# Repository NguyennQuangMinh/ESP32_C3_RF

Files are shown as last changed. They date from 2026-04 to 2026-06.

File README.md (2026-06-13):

# ESP32_C3_RF

## 🛠️ Project Overview

This project involves designing a 4-layer PCB using Altium Designer for the ESP32_C3_RF. All components, footprints, schematics, and 3D models were custom-created and assembled with me.

## Design Files 

### 🔹 Reversion History Schematic
<p align="center">
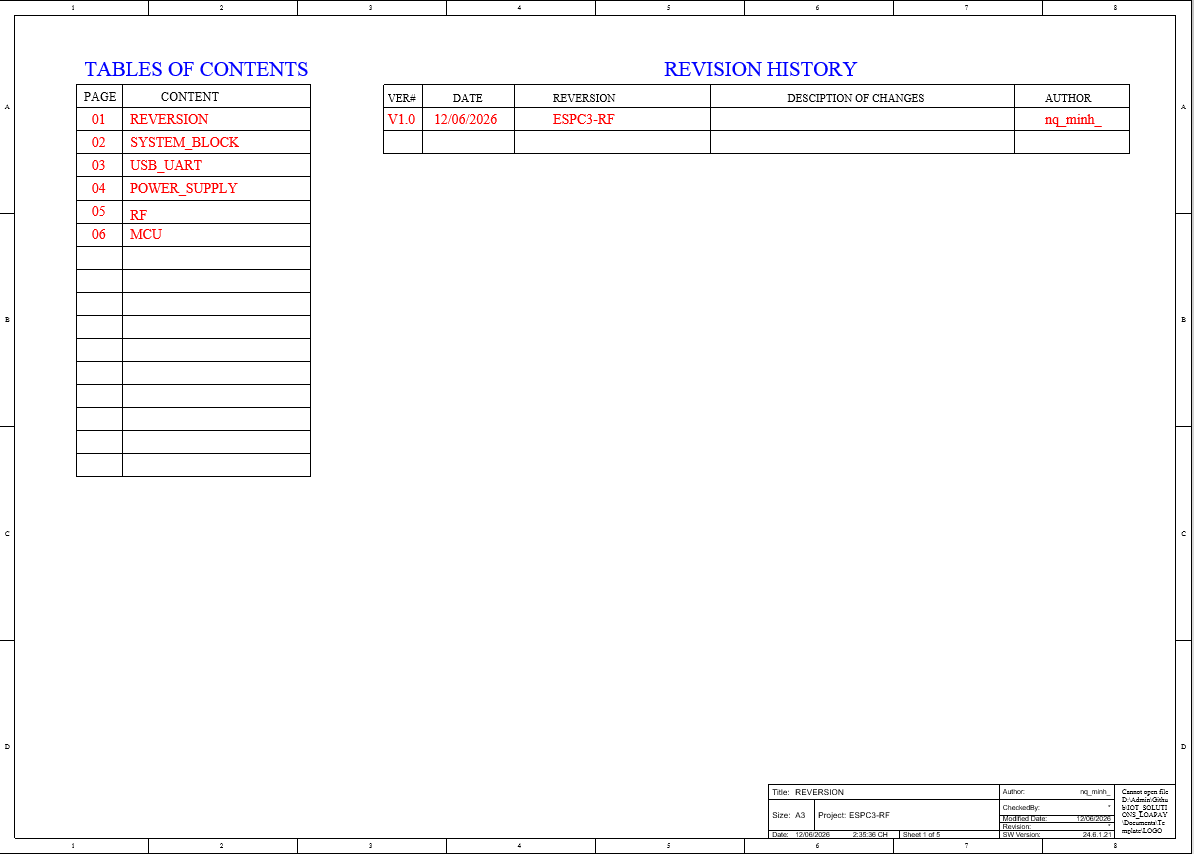
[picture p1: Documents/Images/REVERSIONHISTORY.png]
  
</p>

### 🔹 System Block Schematic
<p align="center">
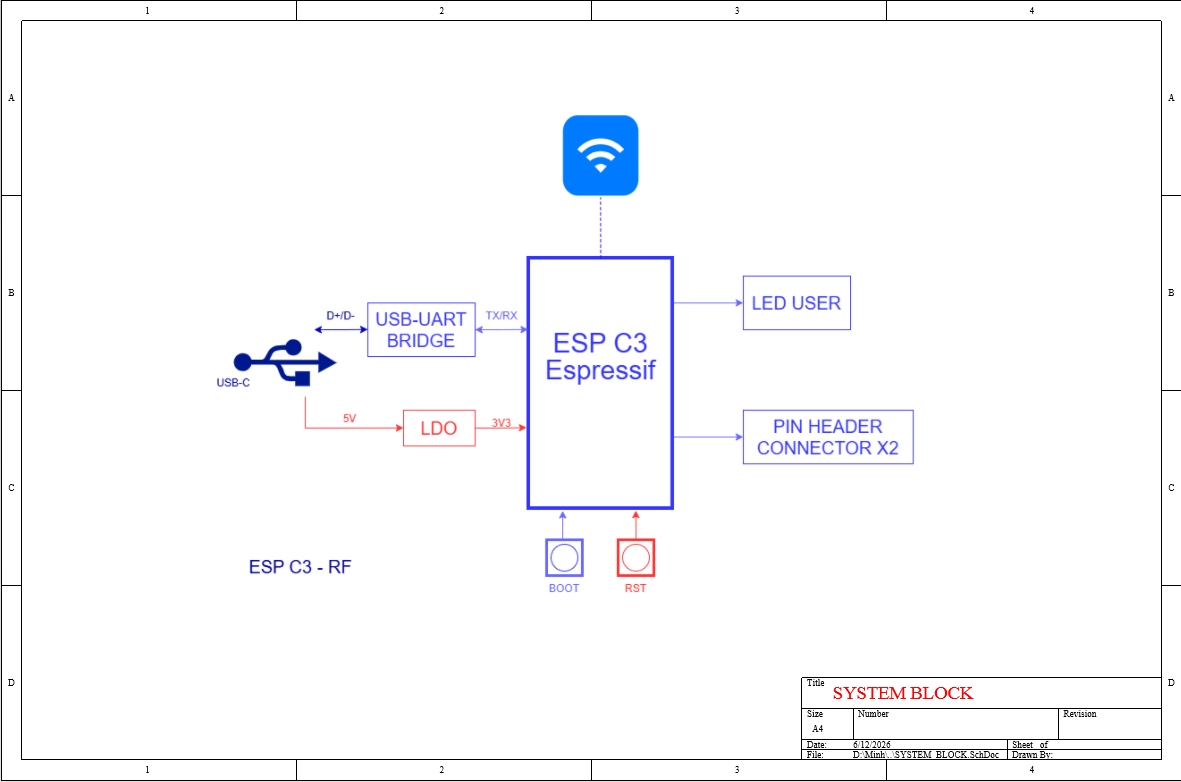
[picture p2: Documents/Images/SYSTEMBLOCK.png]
  
</p>

### 🔹 USB-UART Schematic
<p align="center">
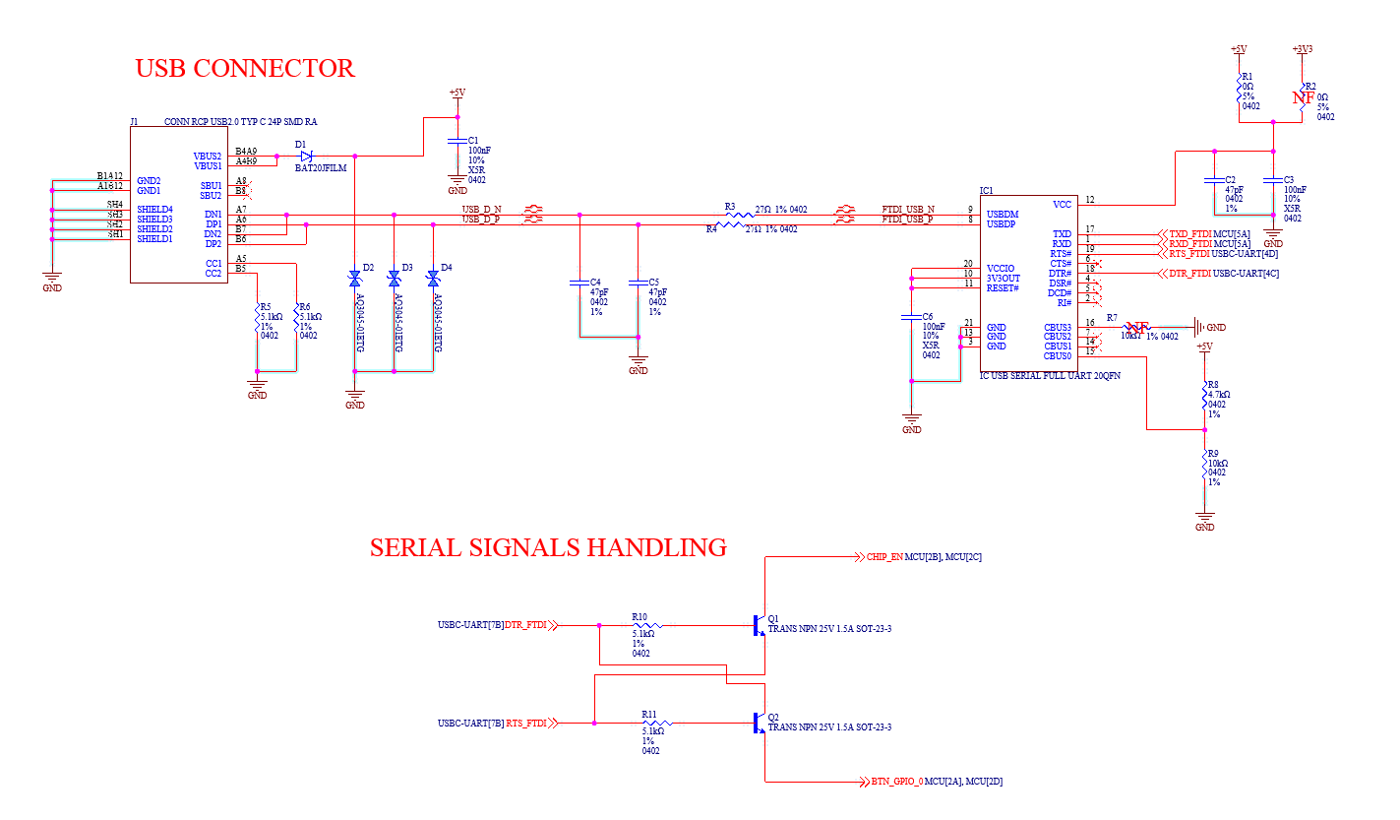
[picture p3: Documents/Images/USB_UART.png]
  
</p>

### 🔹 Power Sharing Schematic
<p align="center">
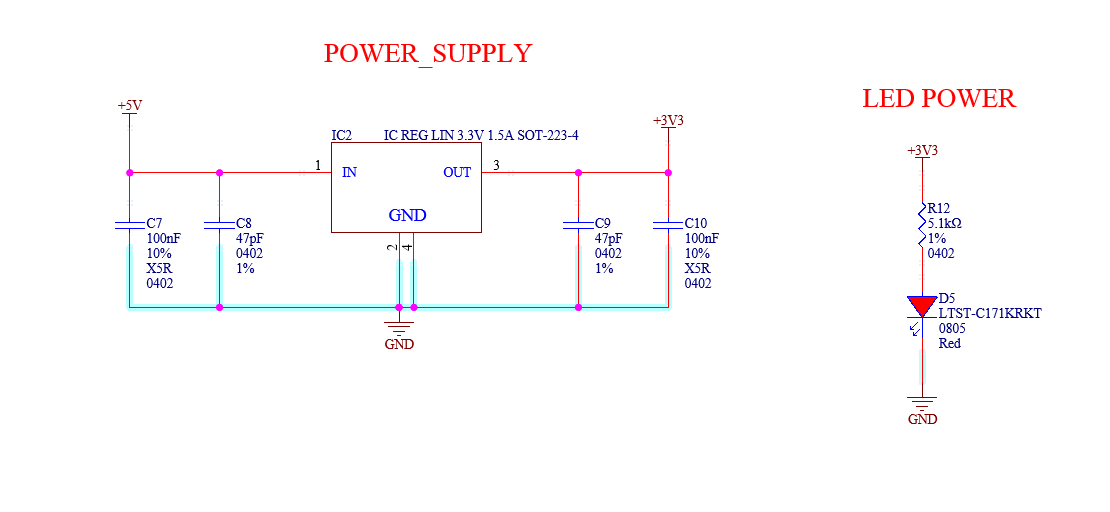
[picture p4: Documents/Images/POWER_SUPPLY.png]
  
</p>

### 🔹 RF 2.4Ghz Antenna Schematic
<p align="center">
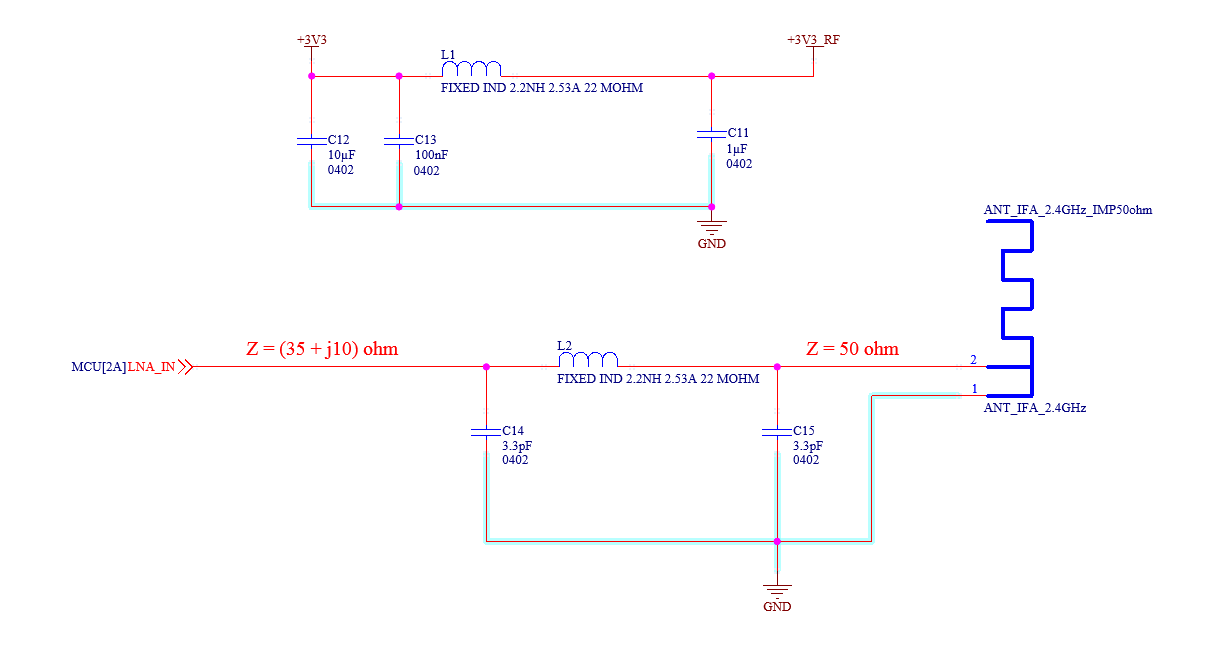
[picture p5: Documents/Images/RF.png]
  
</p>

### 🔹 Peripherals Schematic
<p align="center">
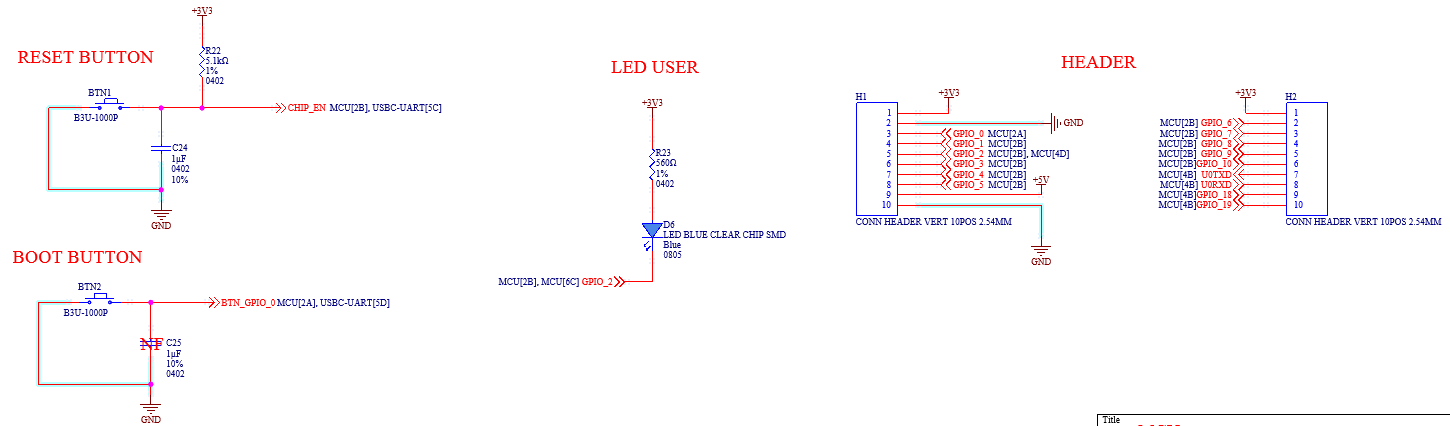
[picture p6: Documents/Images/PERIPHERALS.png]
  
</p>

### 🔹 MCU Schematic
<p align="center">
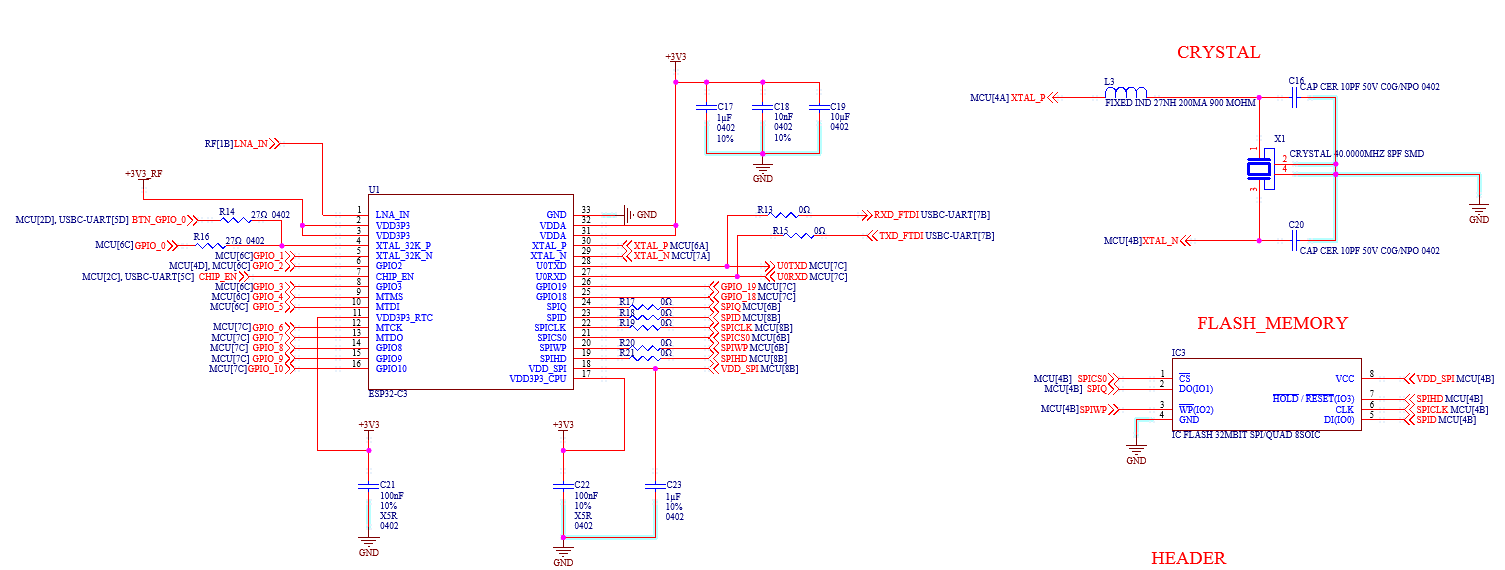
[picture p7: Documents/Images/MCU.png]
  
</p>

### ✅ PCB Overview
<p align="center">
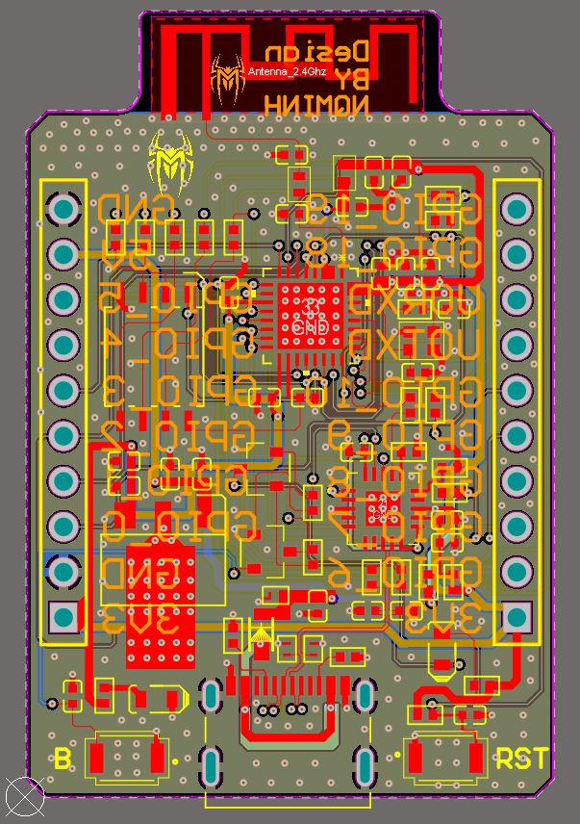
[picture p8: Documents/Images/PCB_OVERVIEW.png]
  
</p>

### ✅ Top Layer
<p align="center">
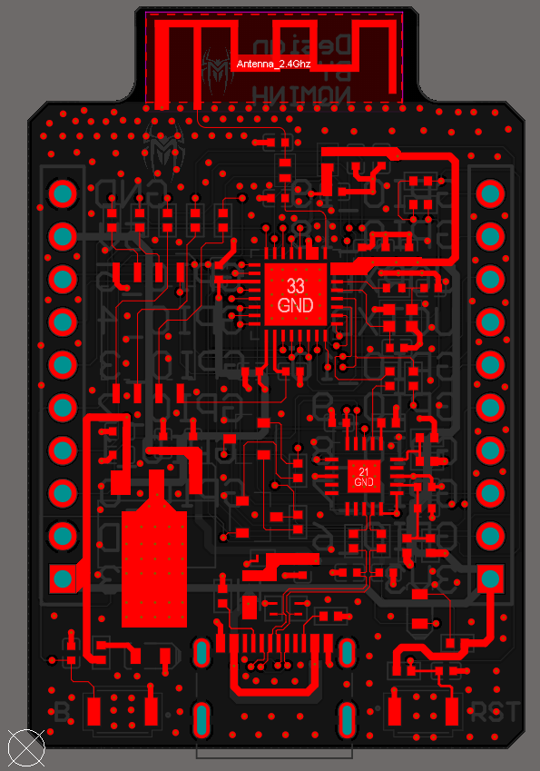
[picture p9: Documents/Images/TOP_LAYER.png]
  
</p>

### ✅ Inner Layer 1
<p align="center">
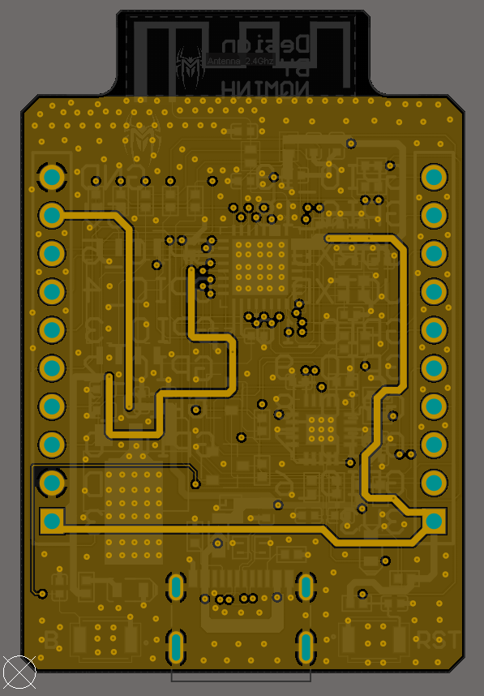
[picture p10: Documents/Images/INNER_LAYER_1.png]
  
</p>

### ✅ Inner Layer 2
<p align="center">
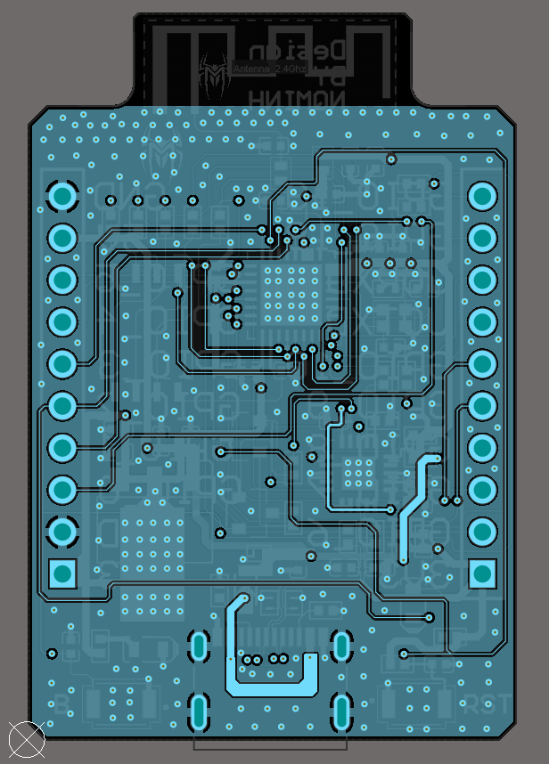
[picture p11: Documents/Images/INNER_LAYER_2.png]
  
</p>

### ✅ Bottom Layer
<p align="center">
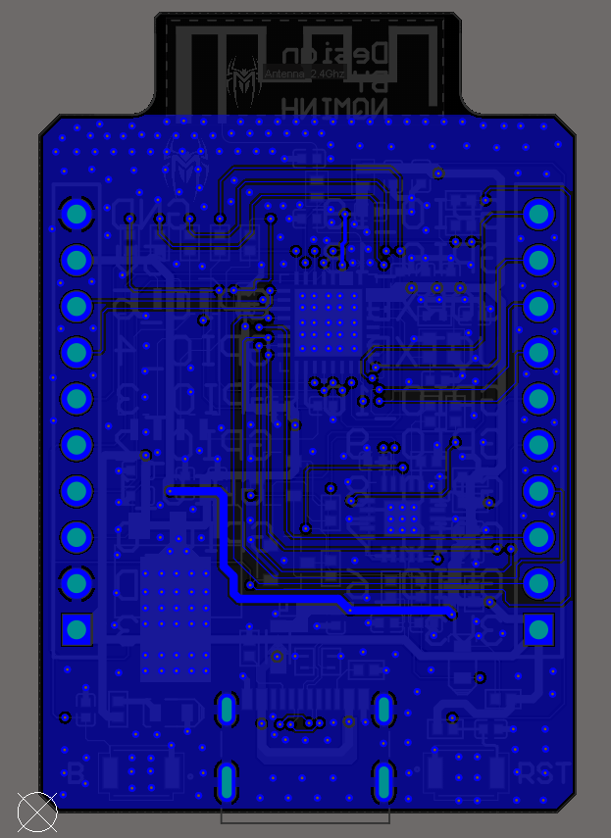
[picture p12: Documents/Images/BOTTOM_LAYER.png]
  
</p>

### ✅ Top Overlay
<p align="center">
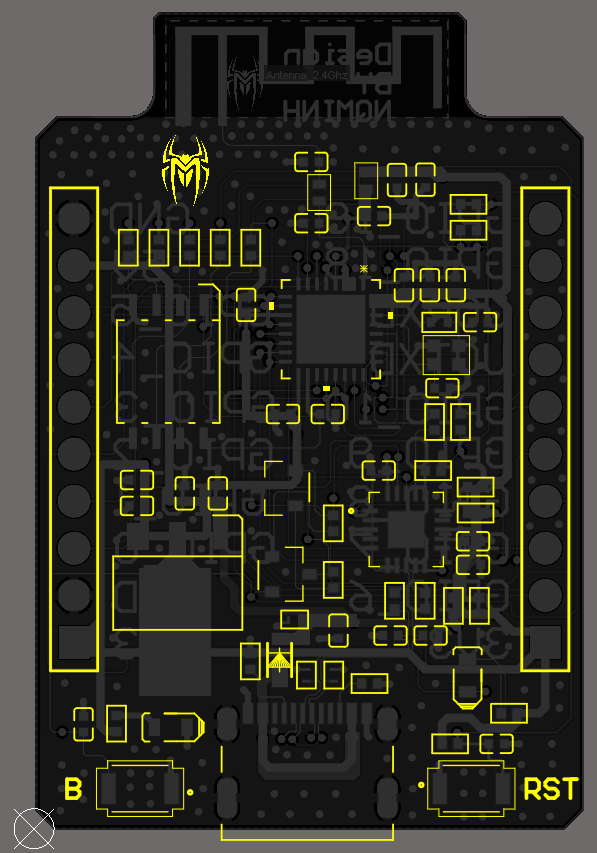
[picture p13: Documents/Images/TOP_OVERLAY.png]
  
</p>

### ✅ Bottom Overlay
<p align="center">
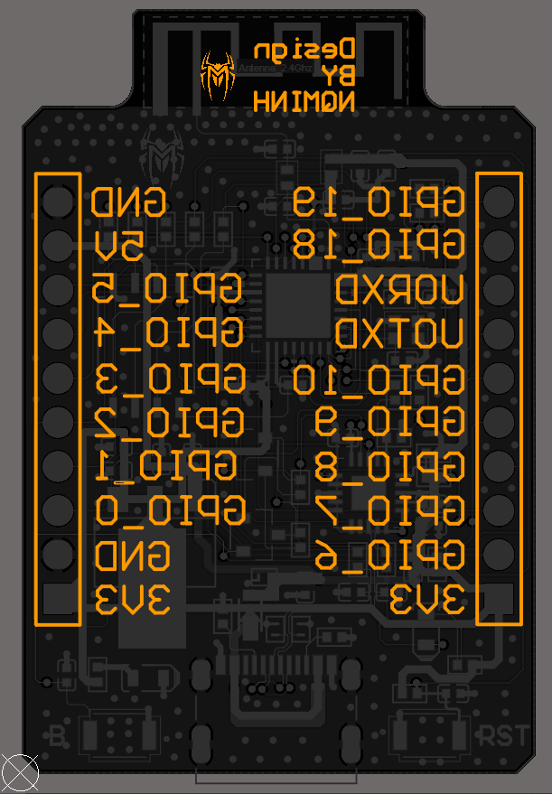
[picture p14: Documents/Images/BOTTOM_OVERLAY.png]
  
</p>

### ✅ 3D Model Top View
<p align="center">
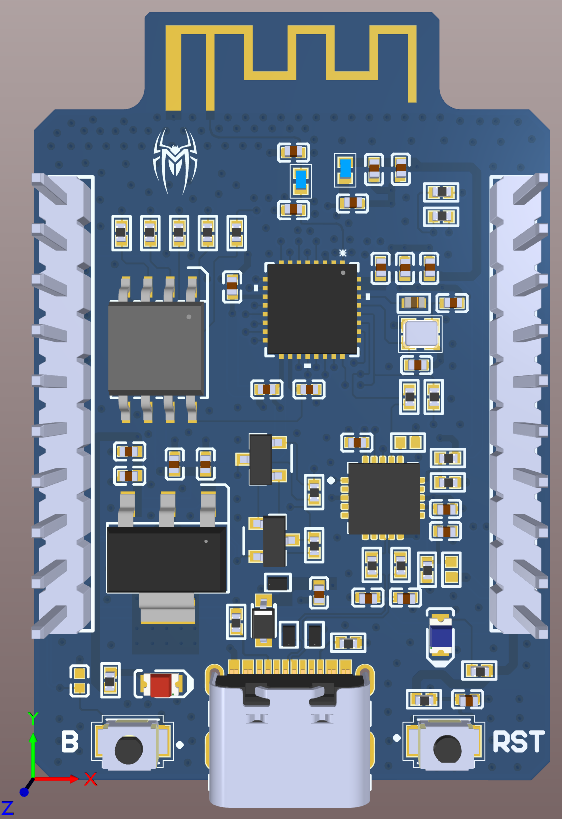
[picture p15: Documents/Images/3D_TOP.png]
  
</p>

### ✅ 3D Model Bottom View
<p align="center">
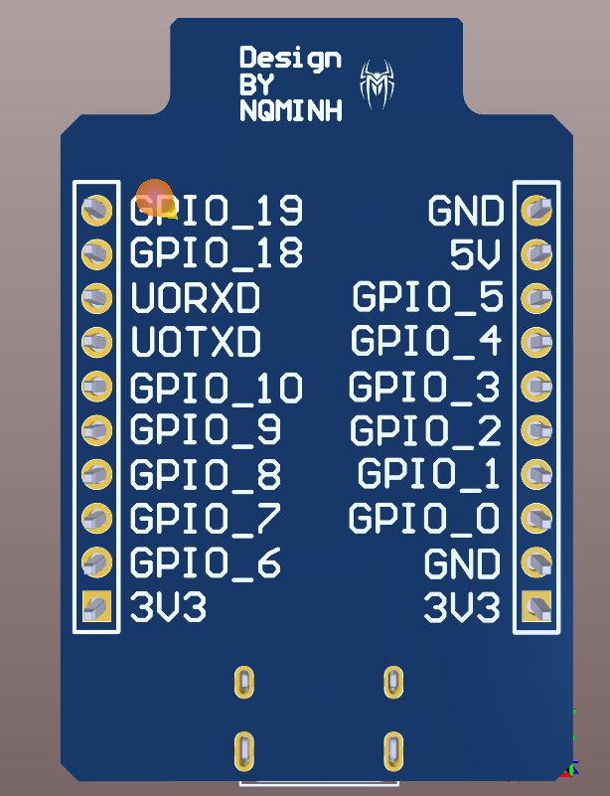
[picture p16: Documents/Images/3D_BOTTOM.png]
  
</p>

### ✅ 3D Model Top View No Body
<p align="center">
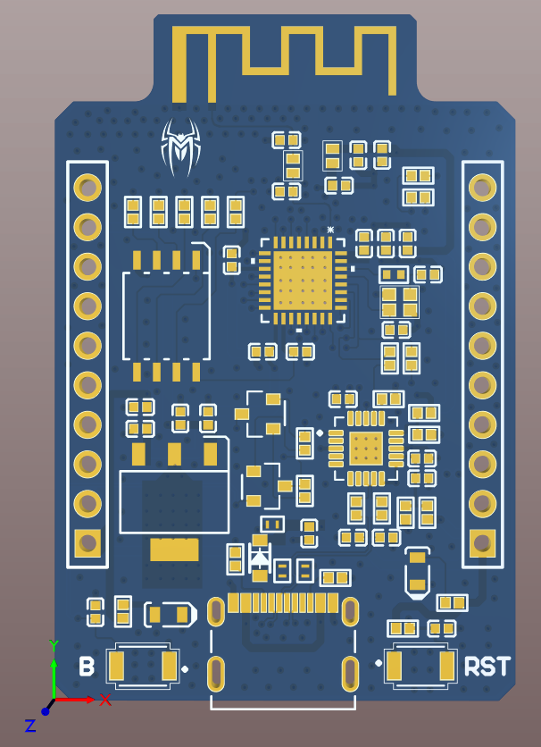
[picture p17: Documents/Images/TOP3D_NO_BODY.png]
  
</p>

## Output Files
### Gerber Files
- Gerber files are used for PCB manufacturing.
### Bill of Materials (BOM)
- Lists all components used in the project.
### NC Drill Files
- Used for drilling holes in the PCB.
### PDF Schematic
- A PDF version of the schematic for easy reference.
### 3D STEP File
- A 3D model of the PCB.
### Assembly Drawings
- Detailed drawings for PCB assembly.
### Pick and Place Files
- Files for automated component placement.

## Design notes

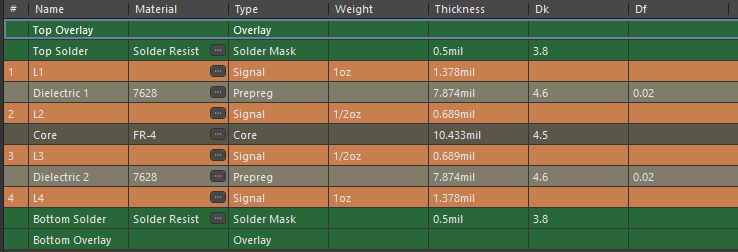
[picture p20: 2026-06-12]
Documents/Images/STACKUP_LAYER.png

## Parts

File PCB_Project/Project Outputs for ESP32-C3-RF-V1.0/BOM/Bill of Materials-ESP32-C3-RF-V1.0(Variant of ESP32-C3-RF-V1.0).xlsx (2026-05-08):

Comment | Description | Designator | Footprint | LibRef | Quantity | LCSC Part | Manufacturer Part Number | Manufacturer | Supplier Part Number | Supplier
ANT_IFA_2.4GHz |  | ANT_IFA_2.4GHz_IMP50ohm | ANT_IFA_2.4GHz | ANT_IFA_2.4GHz | 1
SWITCH TACTILE SPST-NO 0.05A 12V | Switch Tactile N.O. SPST Round Button Solder Tab 12VDC 200000Cycles 1.5N SMD Emboss T/R | BTN1, BTN2 | SW_B3U-1000P | B3U-1000P | 2 | C231329 | B3U-1000P | Omron | SW1020CT-ND | DigiKey
CAP CER 100nF 50V X5R 0402 | 50V 100nF X5R ±10% 0402 Multilayer Ceramic Capacitors MLCC - SMD/SMT ROHS | C1, C3, C6, C7, C10, C13, C21, C22 | C0402 | CC0402KRX5R9BB104 | 8 | C105882 | CC0402KRX5R9BB104 | Yageo Group | 311-3342-2-ND | DigiKey
CAP CER 47PF 50V C0G/NPO 0402 | 50V 47pF NP0 ±1% 0402 Multilayer Ceramic Capacitors MLCC - SMD/SMT ROHS | C2, C4, C5, C8, C9 | C0402 | CC0402FRNPO9BN470 | 5 | C277503 | CC0402FRNPO9BN470 | Yageo Group | 311-1646-1-ND | DigiKey
CAP CER 1UF 10V X5R 0402 | Multilayer Ceramic Capacitors MLCC – SMD/SMT; YAGEO; CC0402KRX5R6BB105; 1 µF; 0402; 10 V; 10 V | C11, C17, C23, C24 | C0402 | CC0402KRX5R6BB105 | 4 | C106254 | CC0402KRX5R6BB105 | Yageo Group | 311-1439-1-ND | DigiKey
CAP CER 10UF 10V X5R 0402 | 10V 10uF X5R ±20% 0402 Multilayer Ceramic Capacitors MLCC - SMD/SMT ROHS | C12, C19 | C0402 | GRM155R61A106ME11D | 2 | C408132 | GRM155R61A106ME11D | Murata | 490-GRM155R61A106ME11DCT-ND | DigiKey
GRM1555C2A3R3CA01D | Cap Ceramic 3.3pF 100V C0G 0.25pF Pad SMD 0402 125C T/R | C14, C15 | C0402 | GRM1555C2A3R3CA01D | 2 | C3861813 | GRM1555C2A3R3CA01D | Murata | 490-7287-1-ND | DigiKey
CAP CER 10PF 50V C0G/NPO 0402 | Ceramic Capacitor, Multilayer, Ceramic, 50V, 1% +Tol, 1% -Tol, C0G, 30ppm/Cel TC, 0.00001uF, Surface Mount, 0402 | C16, C20 | C0402 | CC0402FPNPO9BN100 | 2 | C3896396 | CC0402FPNPO9BN100 | Yageo Group | 13-CC0402FPNPO9BN100CT-ND | DigiKey
CAP CER 10000PF 16V X7R 0402 | Multilayer Ceramic Capacitors MLCC - SMD/SMT 16V 0.01uF X7R 0402 10% | C18 | C0402 | CC0402KRX7R7BB103 | 1 | C327009 | CC0402KRX7R7BB103 | Yageo Group | 311-1042-1-ND | DigiKey
BAT20JFILM | BAT20J Series 23 V 1 A Surface Mount Switching Schottky Diode - SOD-323 | D1 | SOD-323 | BAT20JFILM | 1 | C155590 | BAT20JFILM | STMicroelectronics | 497-3381-1-ND | DigiKey
TVS DIODE 5.3VWM 12VC SOD882 | Bi 30Kv 5V 0.35Pf Automotve Tvs Sod882/ T&r Rohs Compliant: Yes |Littelfuse AQ3045-01ETG | D2, D3, D4 | RTVS_SOD882_LTF-L | AQ3045-01ETG | 3 |  | AQ3045-01ETG | Littelfuse | F9321CT-ND | DigiKey
LTST-C171KRKT | LED red 0805 wavelength 631nm light intensity 54mcd Front Mounting | D5 | LED_LTST-C171_LTO-L | LTST-C171KRKT | 1 | C284871 | LTST-C171KRKT | Diodes Inc. | 160-1427-1-ND | DigiKey
LED BLUE CLEAR CHIP SMD | LED blue LED0805 wavelength 465~475nm light intensity 28~180mcd vertical sticker | D6 | LED_0805_BLUE | LTST-C171TBKT | 1 | C98225 | LTST-C171TBKT | Diodes Inc. | 160-1645-1-ND | DigiKey
CONN HEADER VERT 10POS 2.54MM | Conn Unshrouded Header HDR 10 POS 2.54mm Solder ST Top Entry Thru-Hole Bag | H1, H2 | Header 1*10 2.54mm | PH1-10-UA | 2 | C3330527 | PH1-10-UA | Adam Tech | 2057-PH1-10-UA-ND | DigiKey
IC USB SERIAL FULL UART 20QFN | Tape & Reel (TR) 2006 UART USB 2.0 interface controller 3.3V~5V 4mm 8mA 12Mbps | IC1 | QFN50P400X400X80-21N | FT231XQ-R | 1 | C132159 | FT231XQ-R | FTDI | 768-1128-6-ND | DigiKey
IC REG LIN 3.3V 1.5A SOT-223-4 | 1.5-A, 20-V, low-dropout voltage regulator with reverse current & reverse voltage protection | IC2 | DCY4_TEX-L | TL1963A-33DCYR | 1 | C181262 | TL1963A-33DCYR | Texas Instruments | 296-24897-1-ND | DigiKey
IC FLASH 32MBIT SPI/QUAD 8SOIC | NOR Flash Serial (SPI, Dual SPI, Quad SPI) 3V/3.3V 32M-bit 4M x 8 6ns 8-Pin SOIC T/R | IC3 | SOIC-8_5P28X5P28_WIN-L | W25Q32JVSSIQ TR | 1 | C179173 | W25Q32JVSSIQ TR | Winbond | 256-W25Q32JVSSIQTRCT-ND | DigiKey
CONN RCP USB2.0 TYP C 24P SMD RA | USB Connector, USB Type C, USB 2.0, Receptacle, 16 Ways, Surface Mount, Through Hole Mount | J1 | MOLEX_2171790001 | 217179-0001 | 1 | 2171790001 | 217179-0001 | Molex | 900-2171790001DKR-ND | DigiKey
FIXED IND 2.2NH 2.53A 22 MOHM | General Purpose Inductor, 0.0022uH, 2%, 1 Element, Wirewound-Core, Reflow soldering, 1005/0402 | L1, L2 | INDC1006X60N | LQW15AN2N2G80D | 2 |  | LQW15AN2N2G80D | Murata | 490-LQW15AN2N2G80DCT-ND | DigiKey
FIXED IND 27NH 200MA 900 MOHM | General Purpose Inductor, 0.027uH, 5%, 1 Element, Ceramic-Core, SMD, 0402 | L3 | IND_L-0402_JOT-L | LRC0402CJ27NGV001T | 1 | C17449954 | LRC0402CJ27NGV001T | Knowles | 712-LRC0402CJ27NGV001TCT-ND | DigiKey
TRANS NPN 25V 1.5A SOT-23-3 | TRANS NPN 25V 1.5A SOT23-3 / Bipolar (BJT) Transistor NPN 25 V 1.5 A 100MHz 300 mW Surface Mount SOT-23-3 | Q1, Q2 | TRANS_SS8050-G | SS8050-G | 2 | C3199946 | SS8050-G | Comchip | 641-1790-1-ND | DigiKey
RES 0 OHM JUMPER 1/16W 0402 | GENERAL PURPOSE CHIP RESISTOR Metal Glaze/thick Film, 0.0625W, 0ohm, Surface Mount, 0402 | R1, R13, R15, R17, R18, R19, R20, R21 | R0402 | RC0402JR-070RL | 8 | C60485 | RC0402JR-070RL | Yageo Group | 311-0.0JRCT-ND | DigiKey
RES SMD 27 OHM 1% 1/16W 0402 | 62.5mW Thin Film Resistor ±50ppm/℃ ±1% 27Ω 0402 Chip Resistor - Surface Mount ROHS | R3, R4, R14, R16 | R0402 | RT0402FRE0727RL | 4 |  | RT0402FRE0727RL | Yageo Group | YAG3343CT-ND | DigiKey
RES 5.1kΩ ±1% 62.5mW 0402 | 62.5mW Thick Film Resistors 50V ±100ppm/℃ ±1% 5.1kΩ 0402 Chip Resistor - Surface Mount ROHS | R5, R6, R10, R11, R12, R22 | R0402 | RC0402FR-075K1L | 6 | [NoParam], C105872 | RC0402FR-075K1L | Yageo Group | 311-5.10KLRCT-ND | DigiKey
RES SMD 4.7K OHM 1% 1/16W 0402 | Chip Resistor with Ni/Au Terminations Thick Film 0402 4.7kOhm 1% Paper T/R | R8 | R0402 | AR0402FR-074K7L | 1 | C4042400 | AR0402FR-074K7L | Yageo Group | 13-AR0402FR-074K7LCT-ND | DigiKey
RES SMD 10K OHM 1% 1/16W 0402 | Chip Resistor with Ni/Au Terminations Thick Film 0402 10kOhm 1% Paper T/R | R9 | R0402 | AR0402FR-0710KL | 1 | C4322213 | AR0402FR-0710KL | Yageo Group | 13-AR0402FR-0710KLCT-ND | DigiKey
RES 560 OHM 1% 1/16W 0402 | RC Series 0402 0.063 W 560 Ohm ±1% ±100 ppm/°C SMT Thick Film Chip Resistor | R23 | R0402 | RC0402FR-13560RL | 1 | C4098662 | RC0402FR-13560RL | Yageo Group | 13-RC0402FR-13560RLCT-ND | DigiKey
ESP32-C3 | 400KB 22 3V~3.6V RISC-V 160MHz QFN-32-EP(5x5) Microcontroller Units (MCUs/MPUs/SOCs) ROHS | U1 | ESP-C3 | ESP32-C3 | 1 | C2838500 | ESP32-C3 | Espressif Systems | 1904-ESP32-C3CT-ND | DigiKey
CRYSTAL 40.0000MHZ 8PF SMD | Crystal 40MHz ±10ppm (Tol) ±10ppm (Stability) 8pF 50Ohm 4-Pin CSMD T/R | X1 | OSC_XRCGB40M000F1S1BR0 | XRCGB40M000F1S1BR0 | 1 | C1870451 | XRCGB40M000F1S1BR0 | Murata | 490-XRCGB40M000F1S1BR0CT-ND | DigiKey

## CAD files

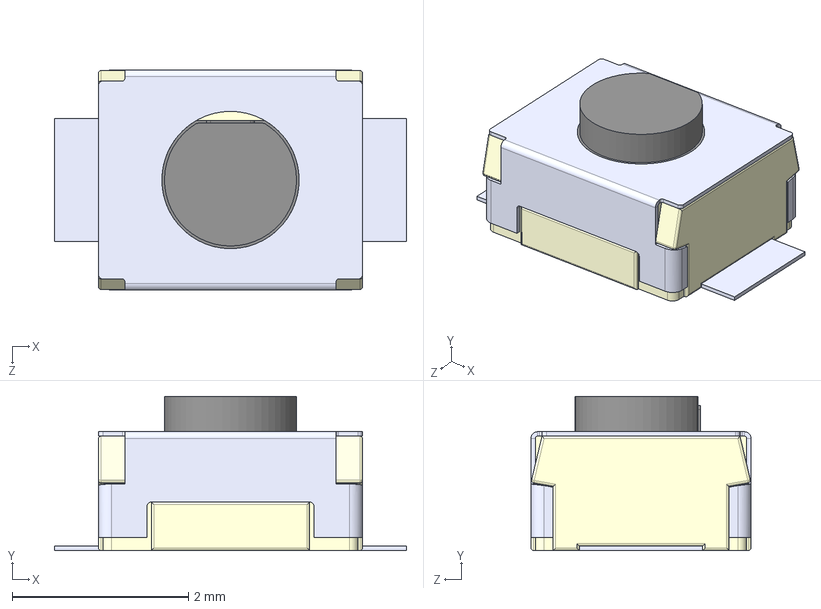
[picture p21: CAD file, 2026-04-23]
Documents/TMP/3D Body/B3U_1000P/B3U-1000P.STEP
4.00 x 1.75 x 2.50 mm

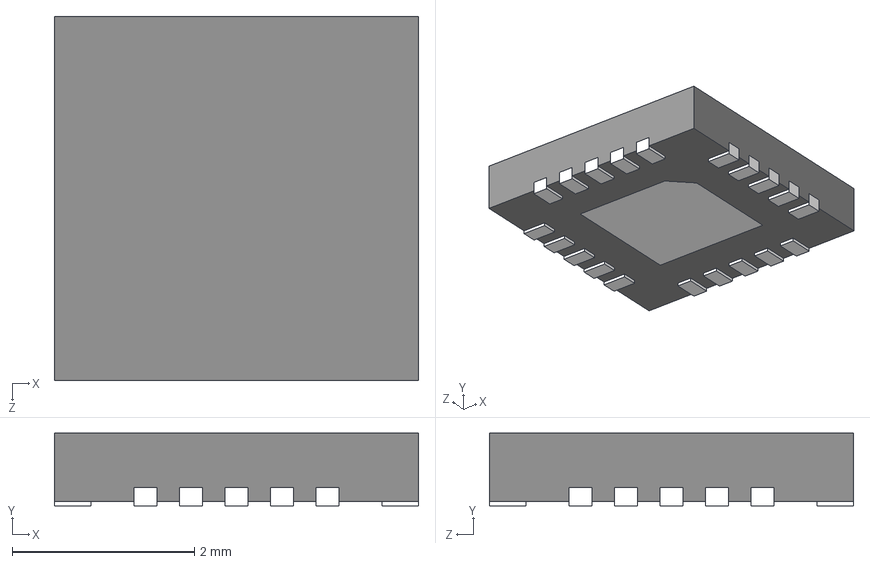
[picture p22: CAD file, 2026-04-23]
Documents/TMP/3D Body/FT231XQ_R/FT231XQ-R.STEP
4.00 x 0.8 x 4.00 mm

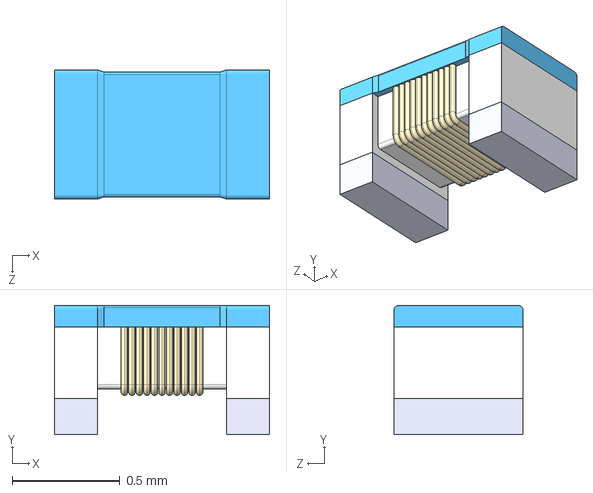
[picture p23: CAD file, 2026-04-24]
Documents/TMP/3D Body/LQW15AN2N2G80D/INDC1006X60N.step
1.00 x 0.6 x 0.6 mm

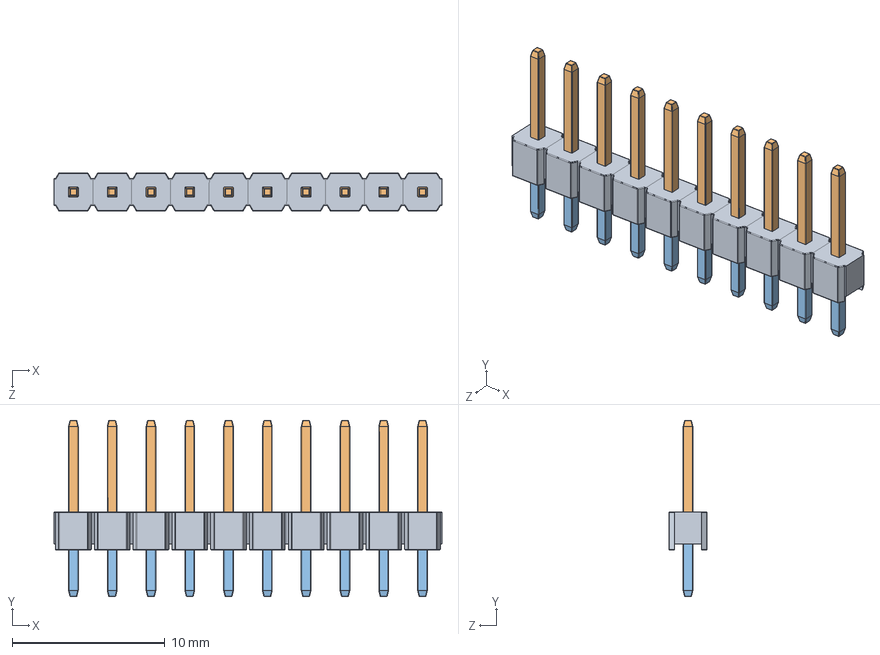
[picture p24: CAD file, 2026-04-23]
Documents/TMP/3D Body/PH1-10-UA.STEP
25.4 x 11.6 x 2.50 mm

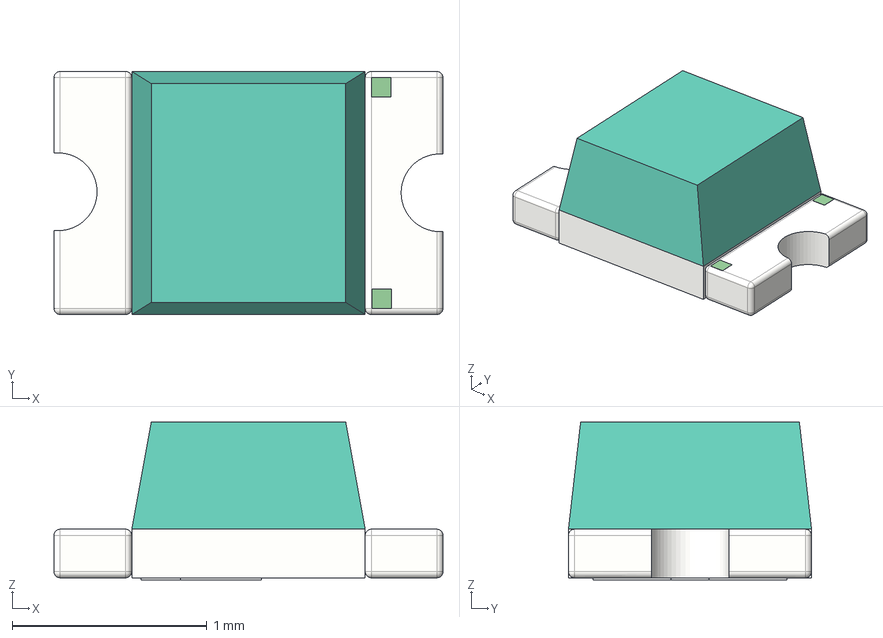
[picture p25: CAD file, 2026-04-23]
Documents/TMP/3D Body/smd-led-0805-3.snapshot.3/LED-0805-glass.step
2.00 x 1.25 x 0.81 mm
ColorGlass

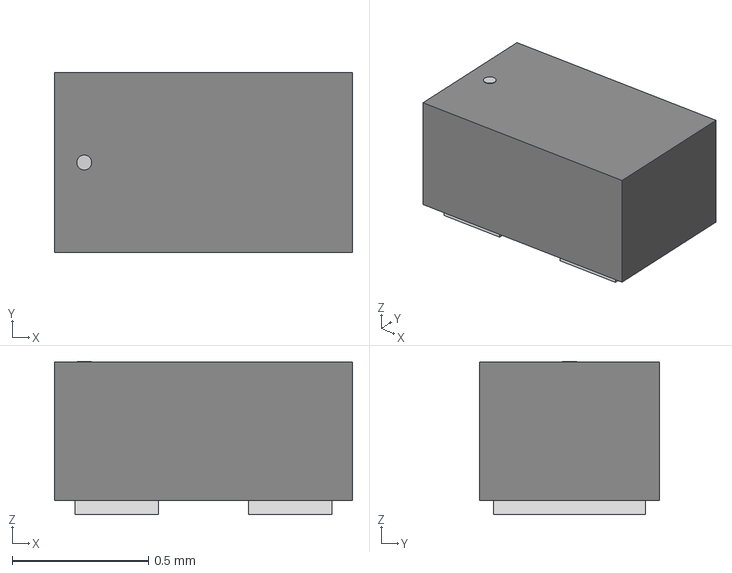
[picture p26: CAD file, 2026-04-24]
Documents/TMP/AQ3045_01ETG/Altium/AQ3045-01ETG/RTVS_SOD882_LTF.step
1.09 x 0.66 x 0.561 mm

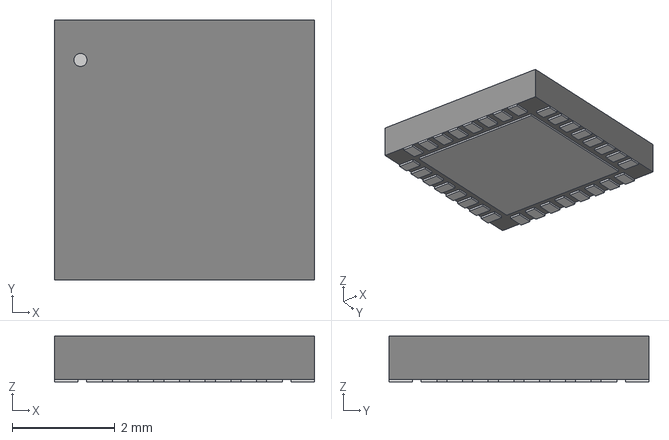
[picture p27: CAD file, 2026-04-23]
Documents/TMP/ESP32_C3/Altium/ESP32-C3/QFN32_5X5_EXP.step
5.05 x 5.05 x 0.892 mm

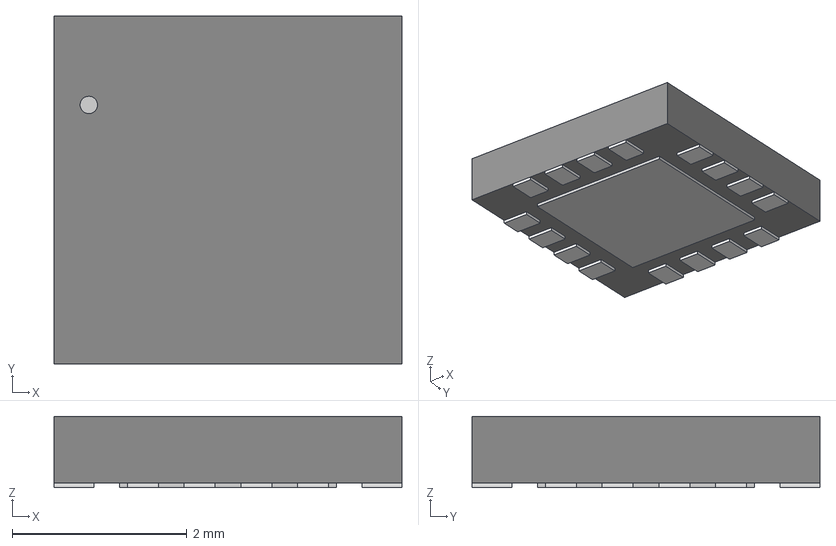
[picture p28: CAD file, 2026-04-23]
Documents/TMP/FT230XQ_R/Altium/FT230XQ-R/QFN-16_FTD.step
3.99 x 3.99 x 0.815 mm

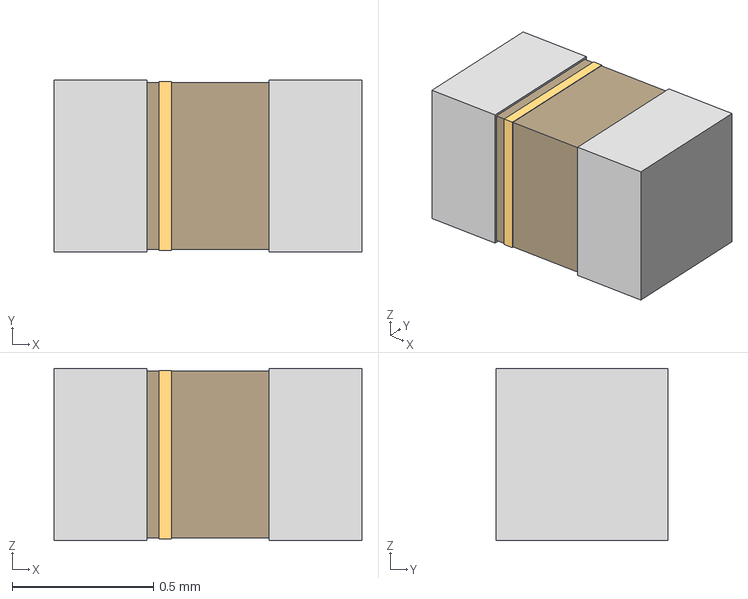
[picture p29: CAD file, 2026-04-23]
Documents/TMP/L_07C27NJV6T/Altium/IND_L-0402_JOT.step
1.09 x 0.61 x 0.61 mm

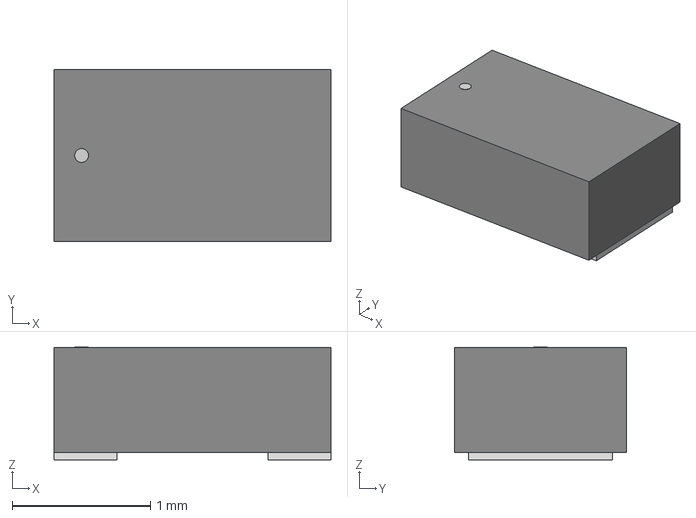
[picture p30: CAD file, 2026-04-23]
Documents/TMP/LTST_C171KRKT/Altium/LTST-C171KRKT/LED_LTST-C171_LTO.step
2.01 x 1.24 x 0.815 mm

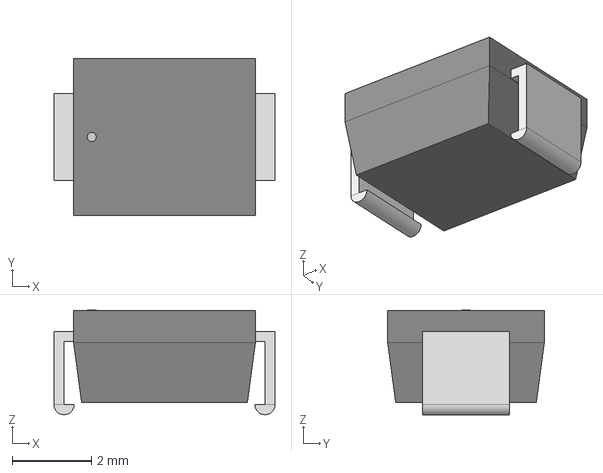
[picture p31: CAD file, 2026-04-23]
Documents/TMP/SMBJ5_0A_TR/Altium/SMBJ5-0A-TR/SMB_STM.step
5.59 x 3.96 x 2.64 mm

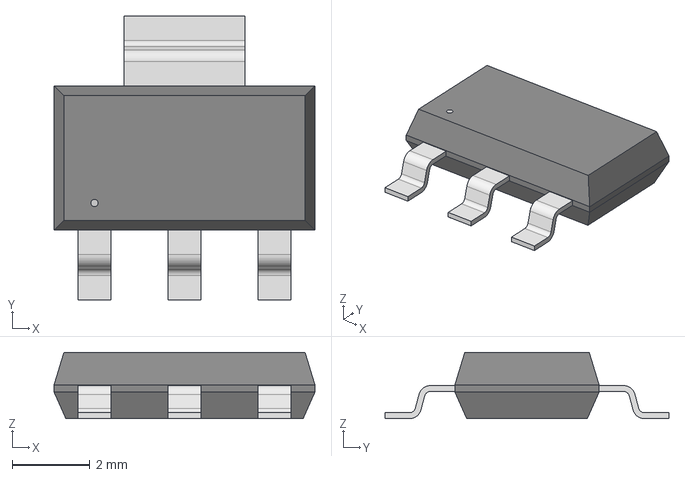
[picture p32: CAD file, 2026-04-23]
Documents/TMP/TL1963A_33DCYR/Altium/TL1963A-33DCYR/DCY4_TEX.step
6.71 x 7.29 x 1.70 mm

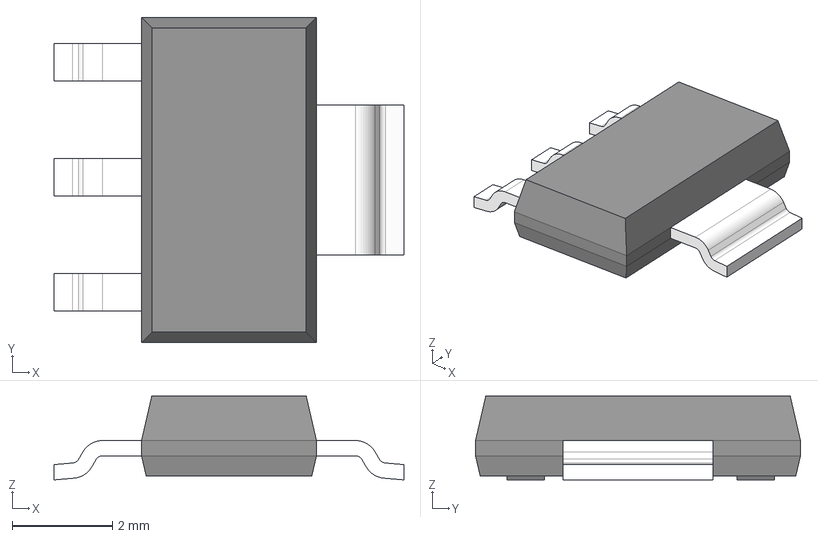
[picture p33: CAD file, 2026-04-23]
Documents/TMP/TL1963A_33DCYR/DCY0004A.stp
7.00 x 6.50 x 1.68 mm
BODY-SOT
LEAD-SOT x 3
LEAD-SOT-WIDE
PIN1-ID

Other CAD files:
Documents/TMP/AQ3045_01ETG/RTVS_SOD882_LTF.step
Documents/TMP/ESP32_C3/QFN32_5X5_EXP.step
Documents/TMP/FT230XQ_R/QFN-16_FTD.step
Documents/TMP/L_07C27NJV6T/IND_L-0402_JOT.step
Documents/TMP/SMBJ5_0A_TR/SMB_STM.step
Documents/TMP/3D Body/2171790001/2171790001.STEP
Documents/TMP/3D Body/C0402C152J5GACTU.STEP
Documents/TMP/3D Body/PH1-10-UA.STL
Documents/TMP/3D Body/SS8050-G--3DModel-STEP-1.STEP
Documents/TMP/3D Body/smd-led-0805-3.snapshot.3/LED-0805-blue.step
Documents/TMP/3D Body/smd-led-0805-3.snapshot.3/LED-0805-emerald.step
Documents/TMP/3D Body/smd-led-0805-3.snapshot.3/LED-0805-green.step
Documents/TMP/3D Body/smd-led-0805-3.snapshot.3/LED-0805-orange.step
Documents/TMP/3D Body/smd-led-0805-3.snapshot.3/LED-0805-red.step
Documents/TMP/3D Body/smd-led-0805-3.snapshot.3/LED-0805-yellow.step
Documents/TMP/W25Q32JVSSIQ/Altium/W25Q32JVSSIQ/SOIC-8_5P28X5P28_WIN.step
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

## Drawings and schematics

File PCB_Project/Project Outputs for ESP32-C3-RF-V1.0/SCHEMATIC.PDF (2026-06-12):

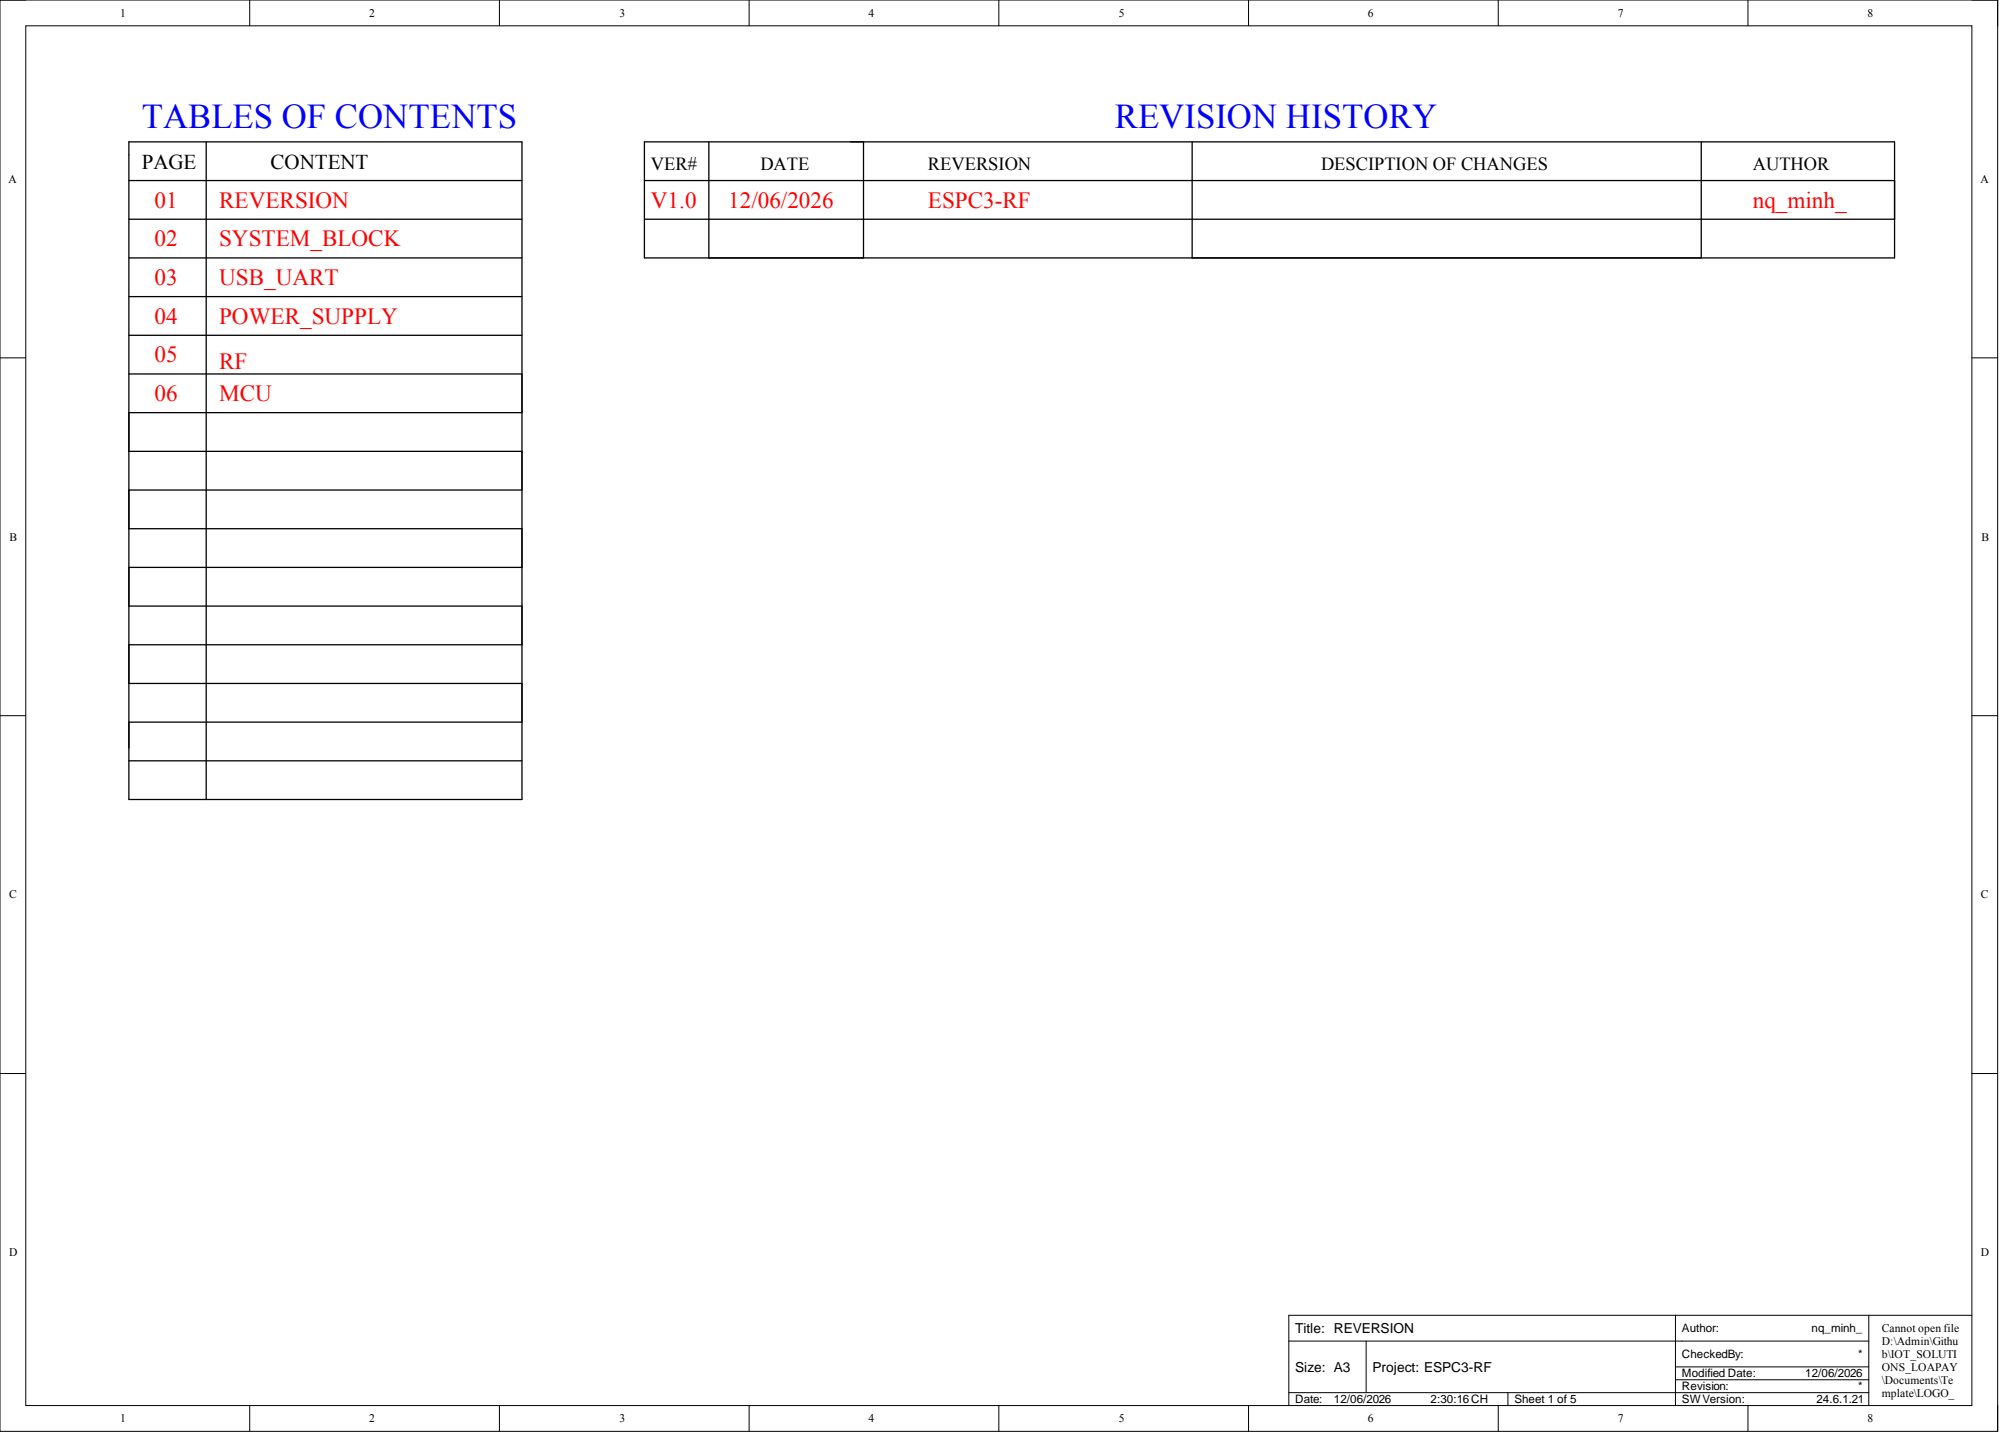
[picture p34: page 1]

02 | SYSTEM_BLOCK
03 | USB_UART
04 | POWER_SUPPLY
05 | RF
06 | MCU

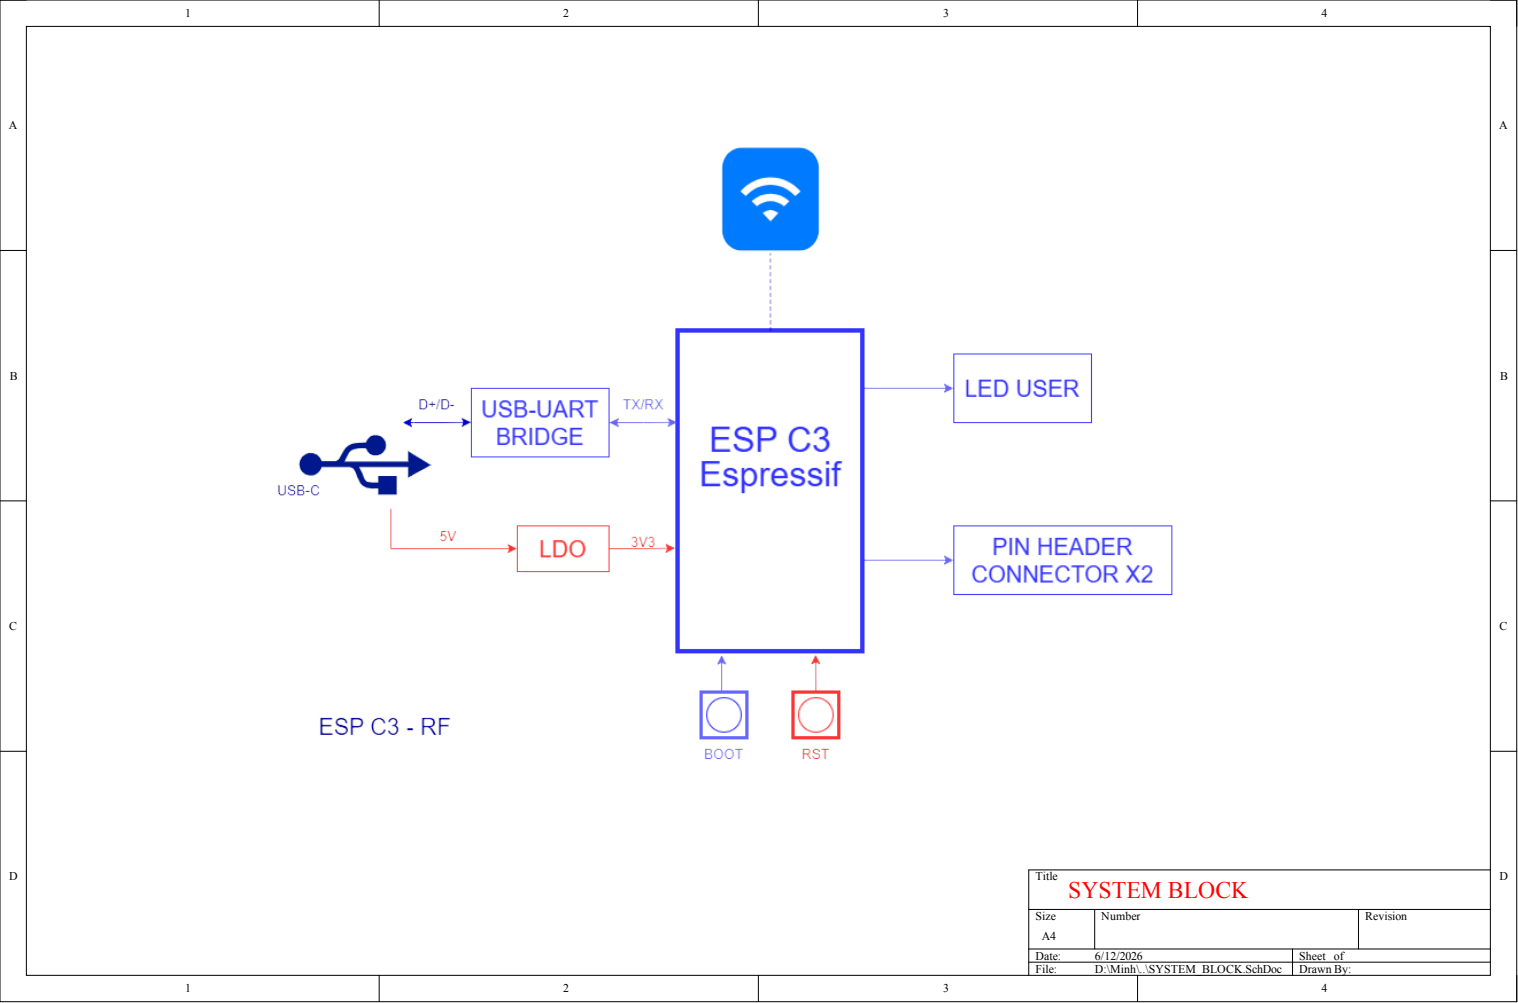
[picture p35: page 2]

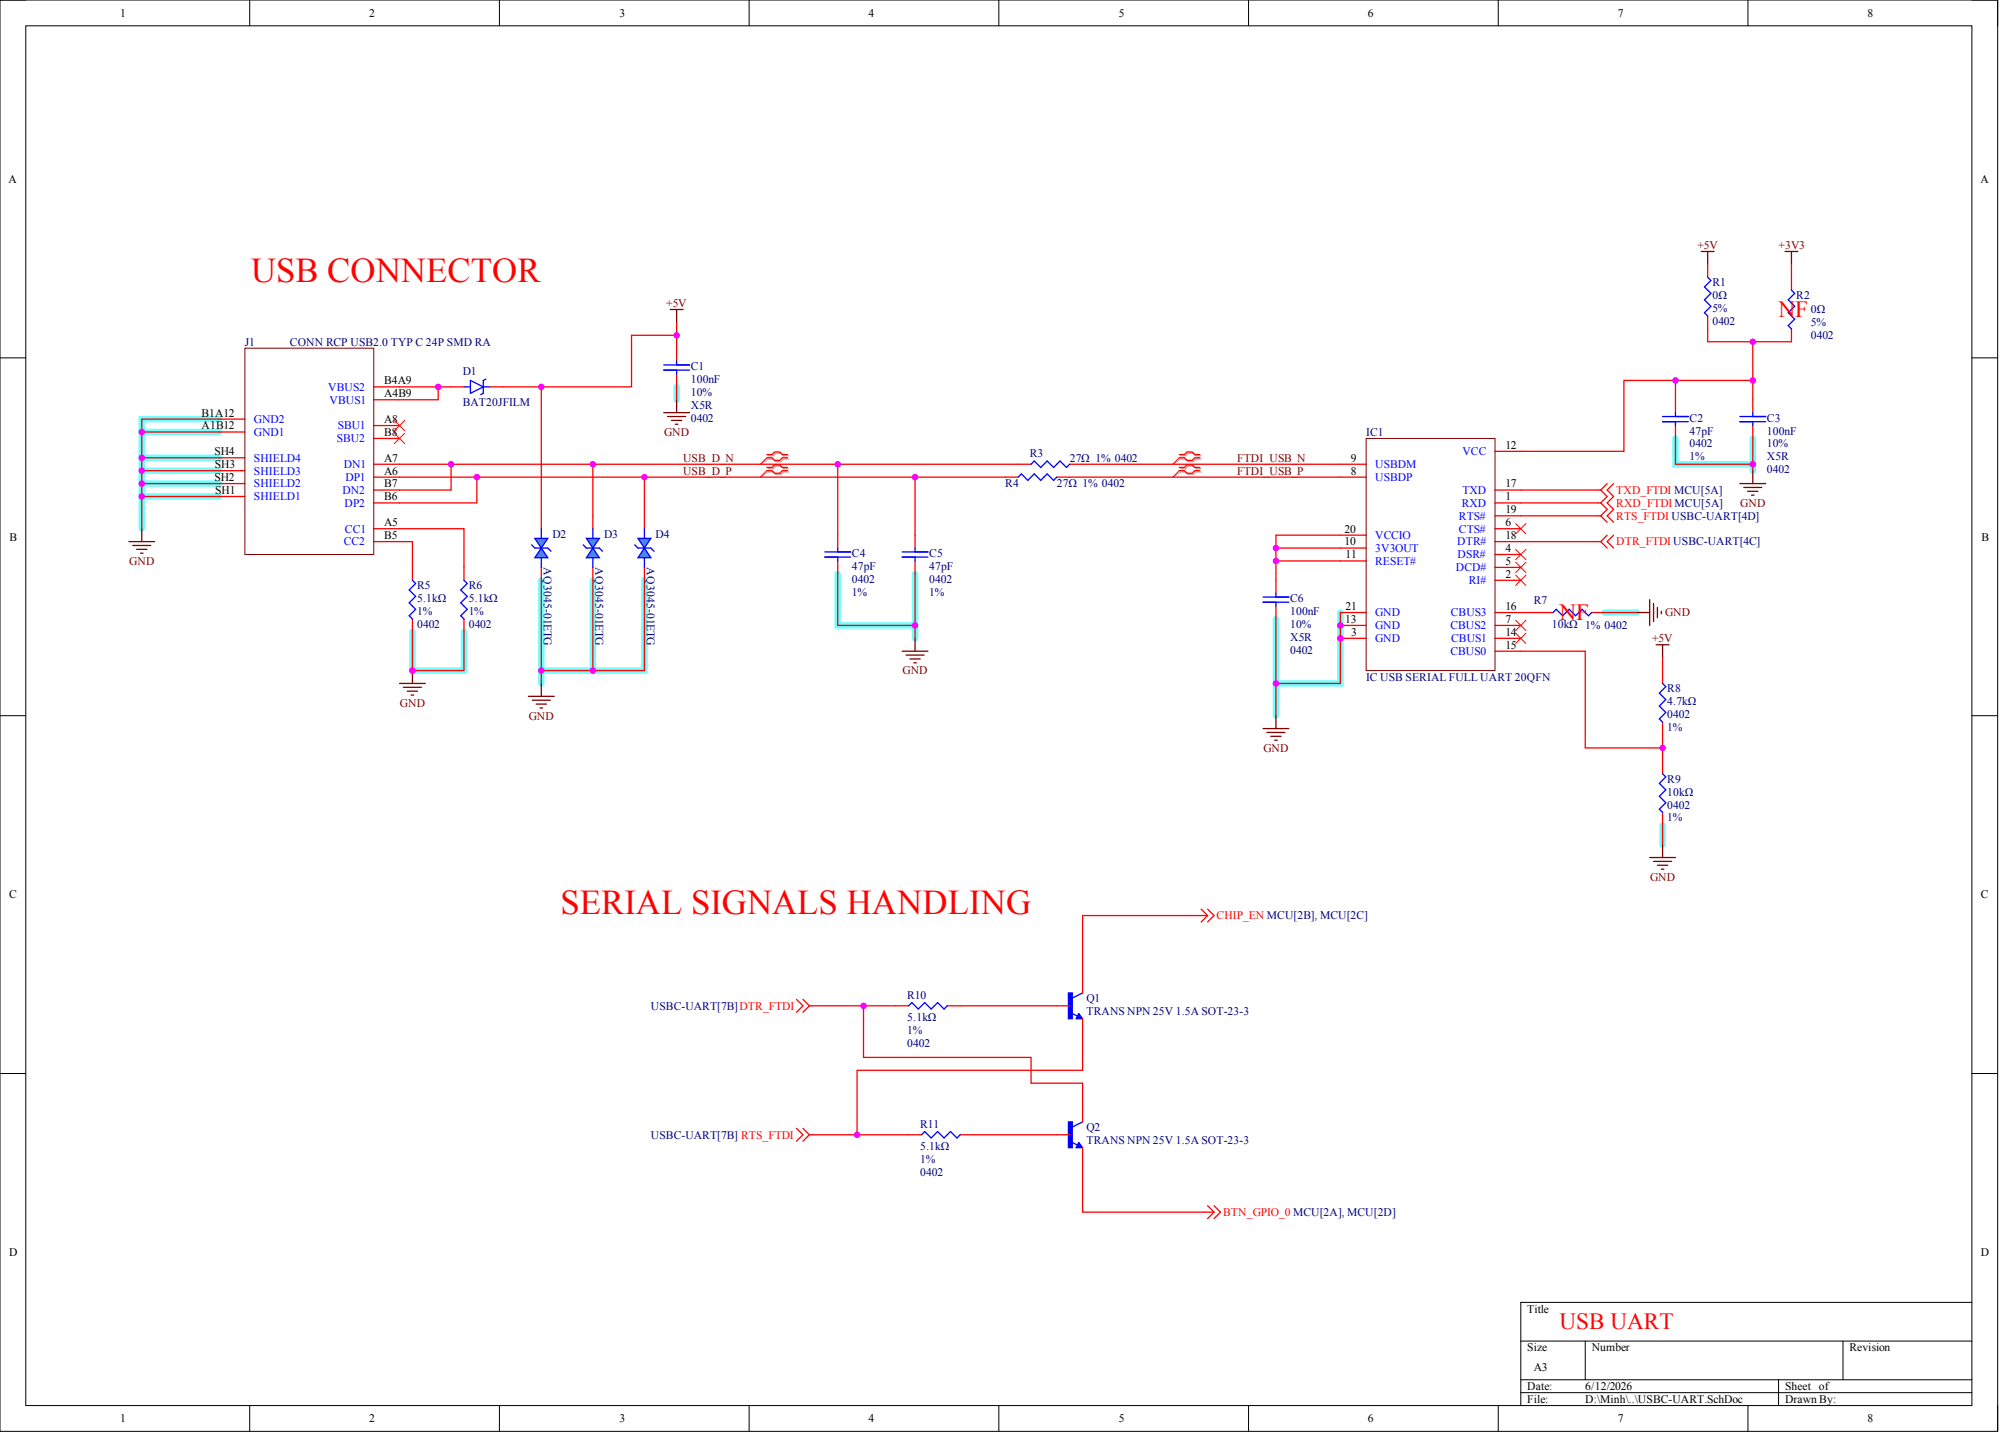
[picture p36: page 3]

1 0
1 1

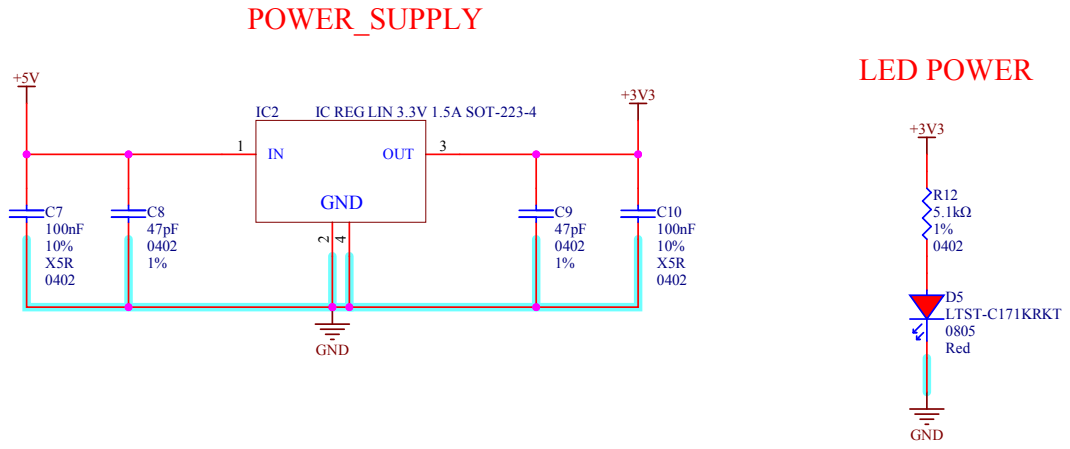
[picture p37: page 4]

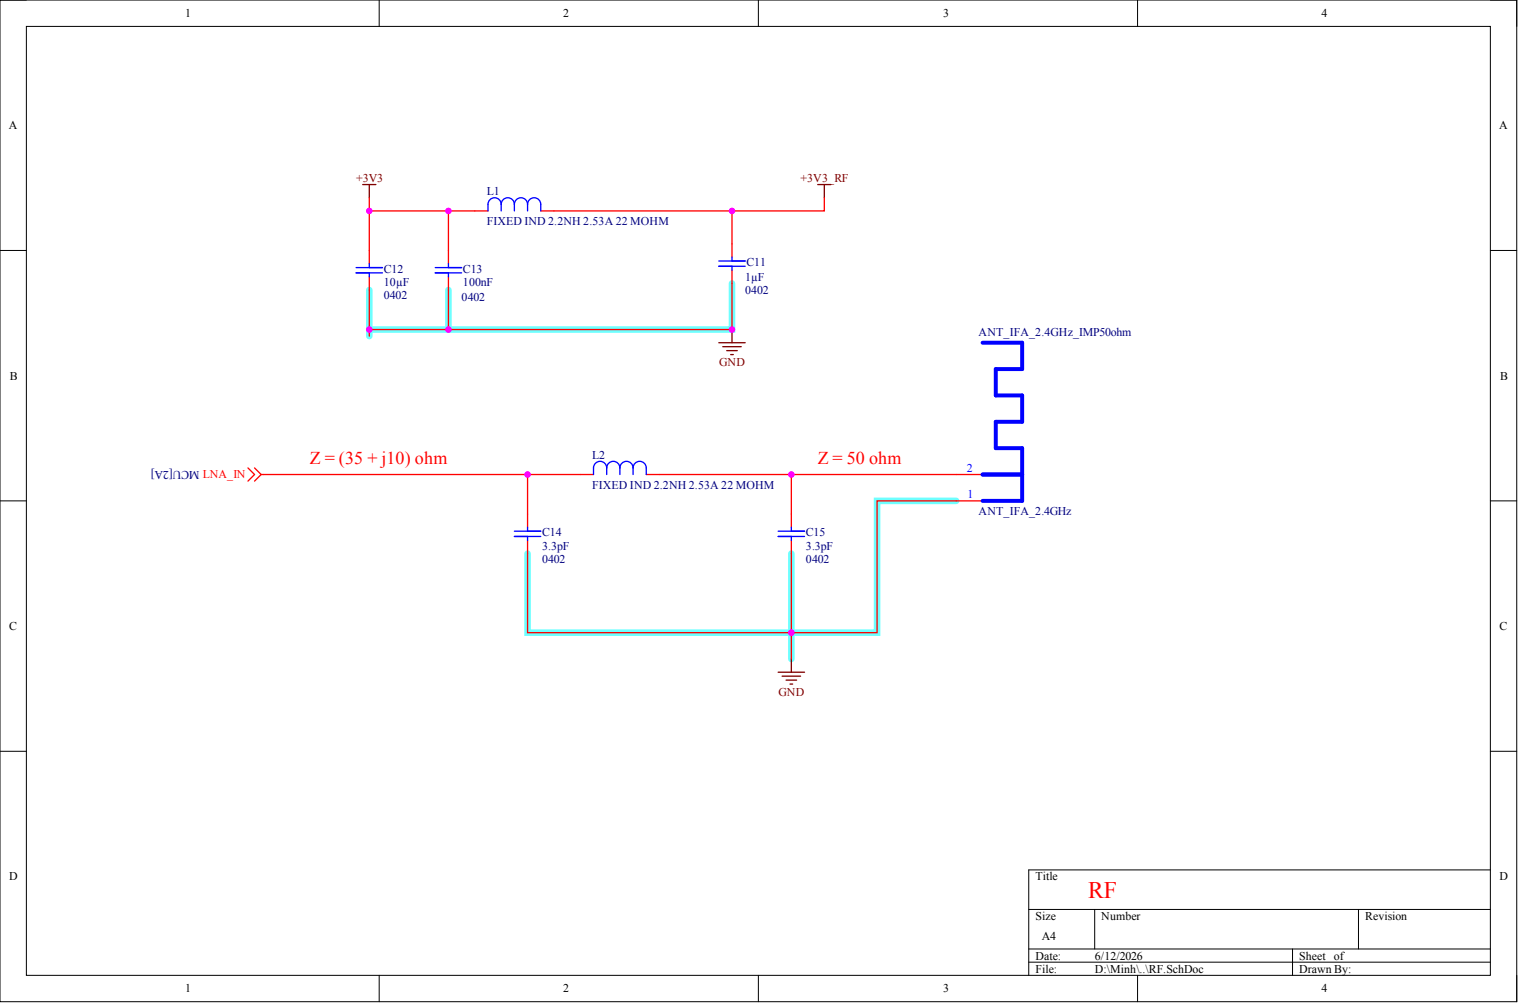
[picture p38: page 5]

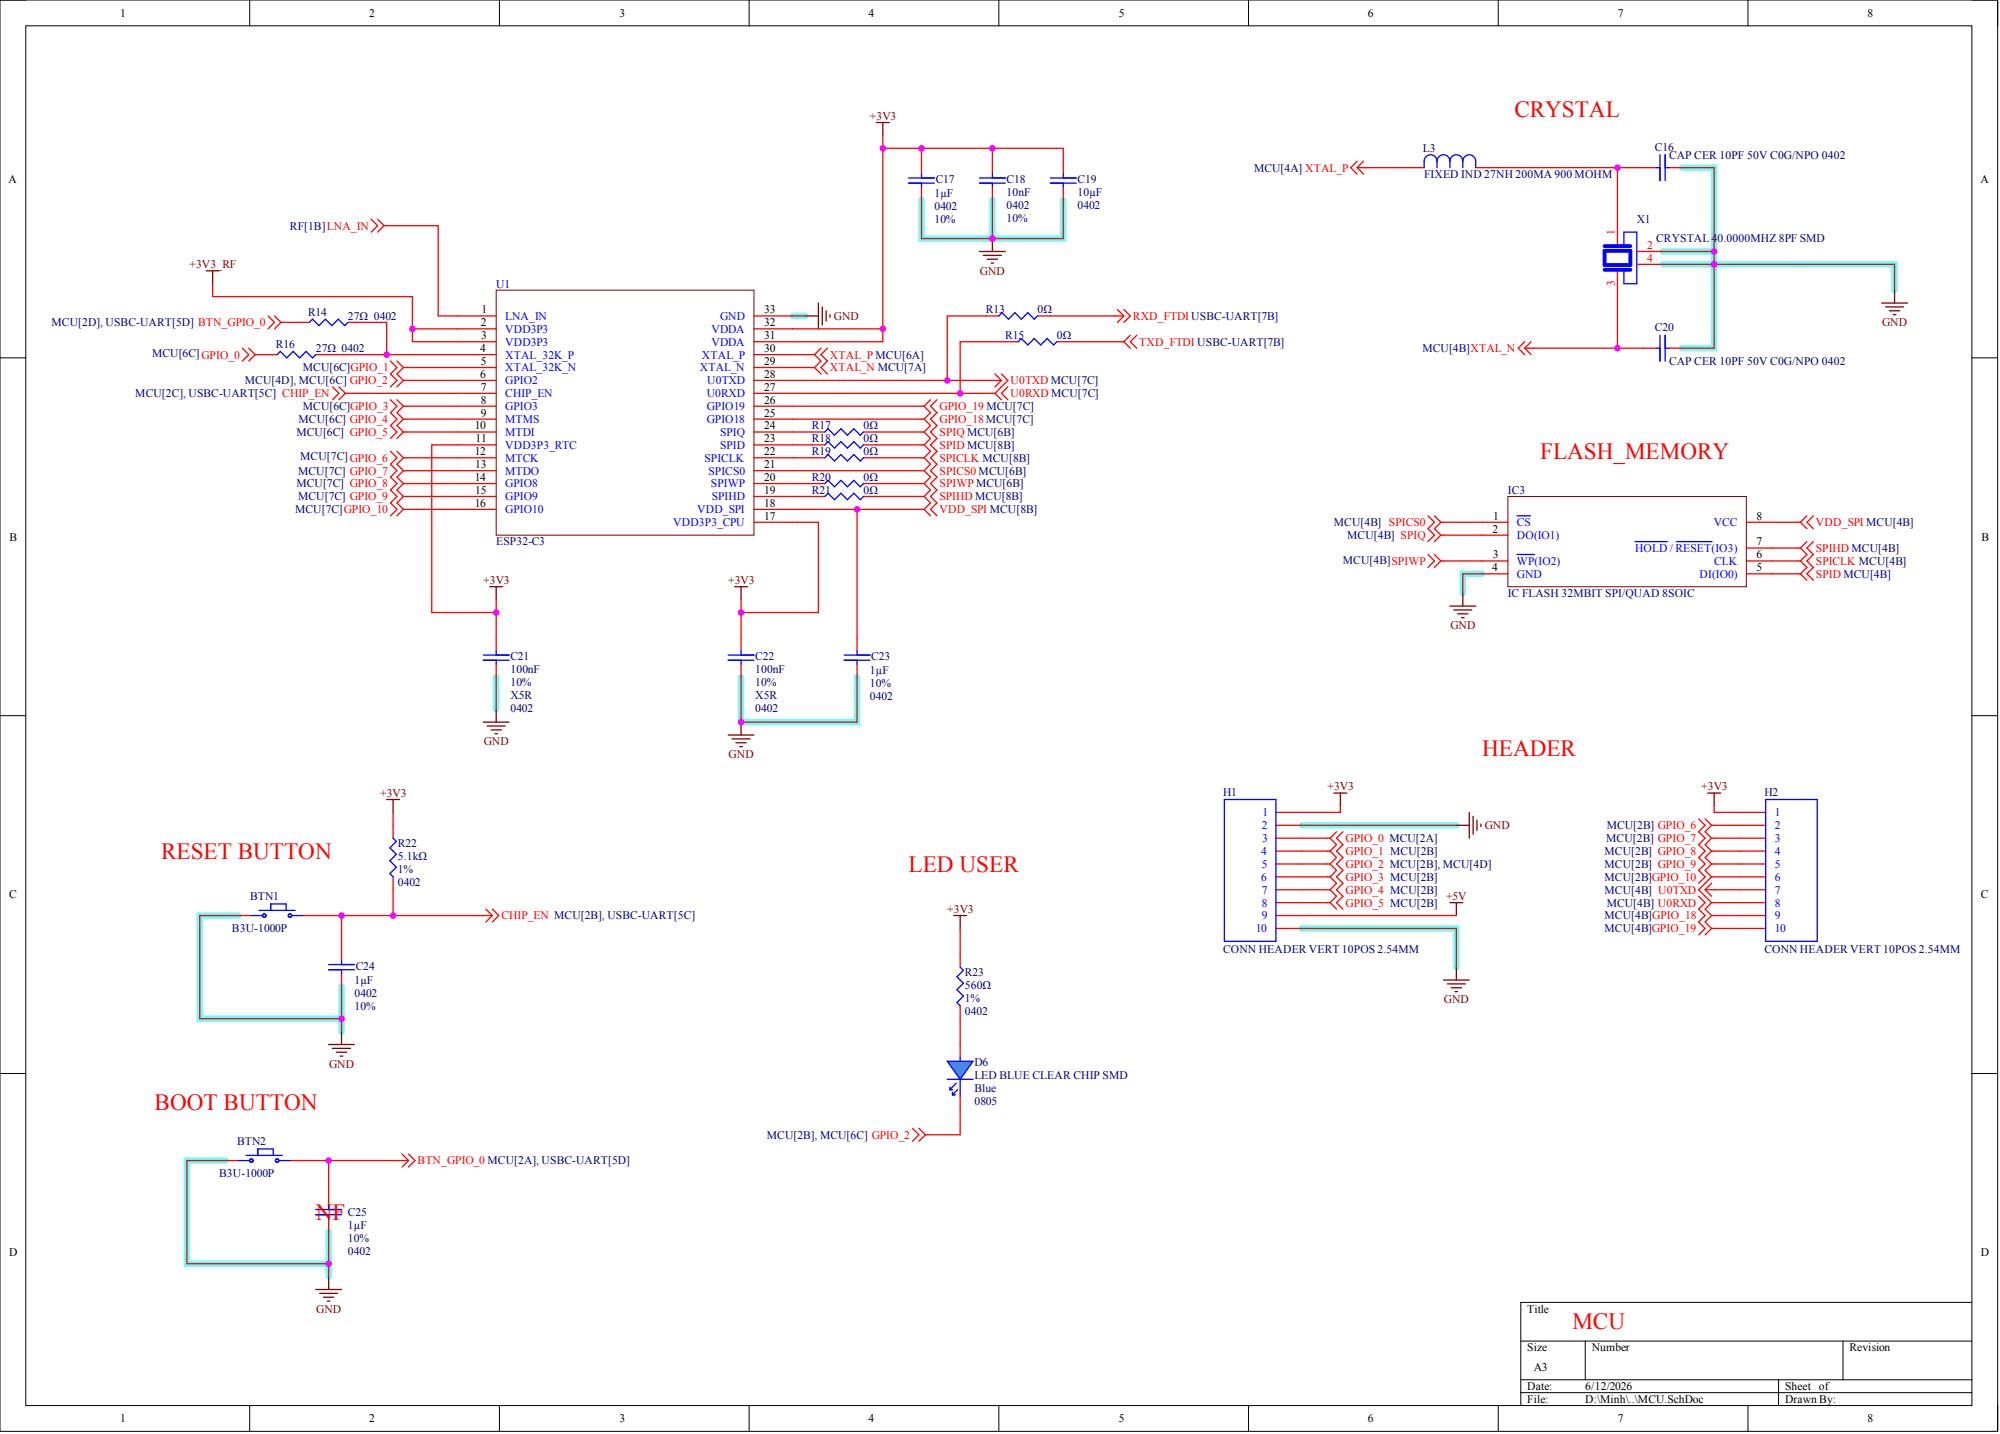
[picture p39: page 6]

VDD3P3 3
XTAL_32K_P 4 | XTAL_P MCU[6A] XTAL_N MCU[7A]

IC FLASH 32MBIT SPI/QUAD 8SOIC

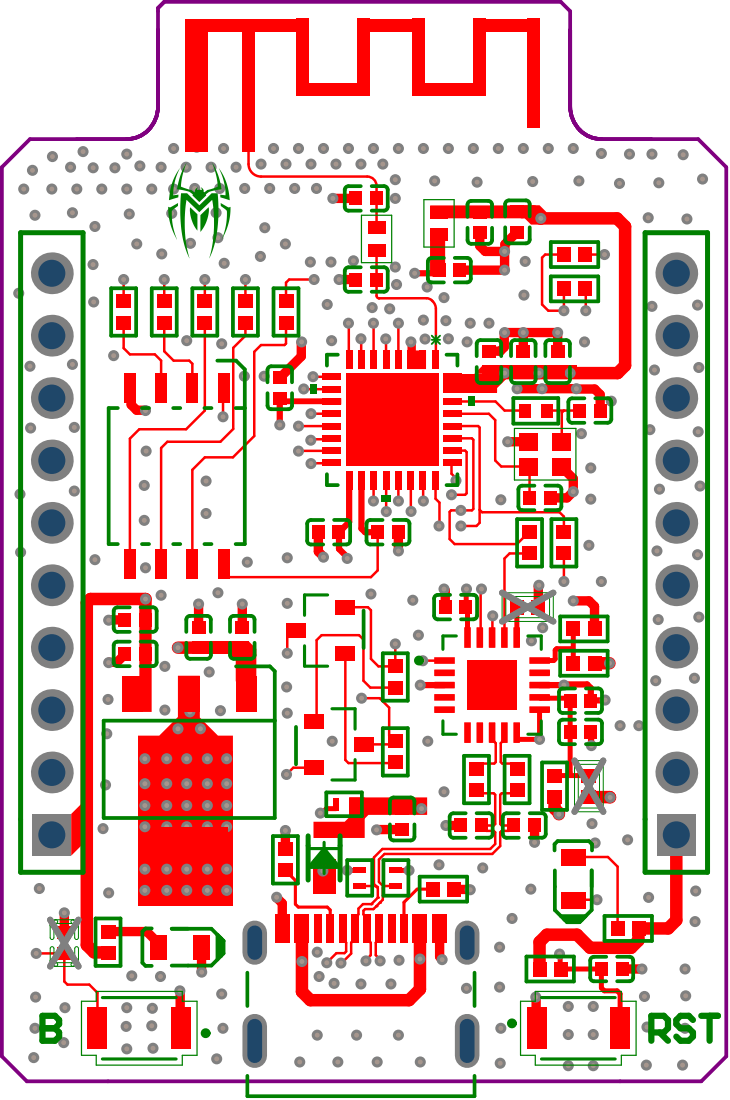
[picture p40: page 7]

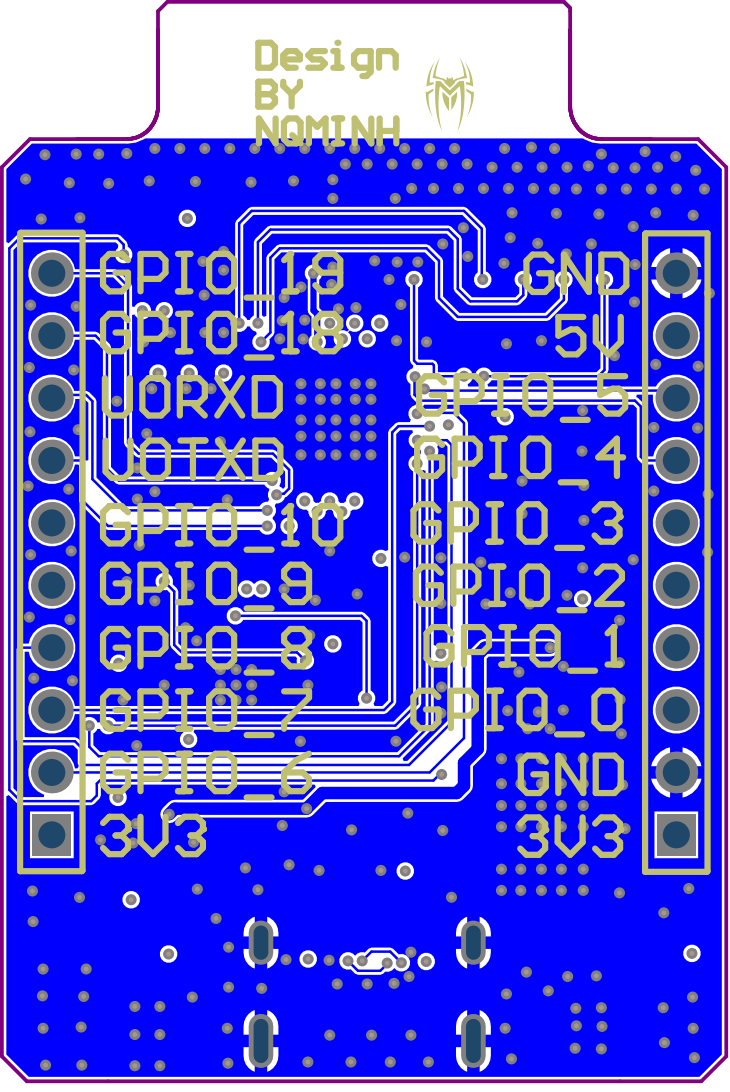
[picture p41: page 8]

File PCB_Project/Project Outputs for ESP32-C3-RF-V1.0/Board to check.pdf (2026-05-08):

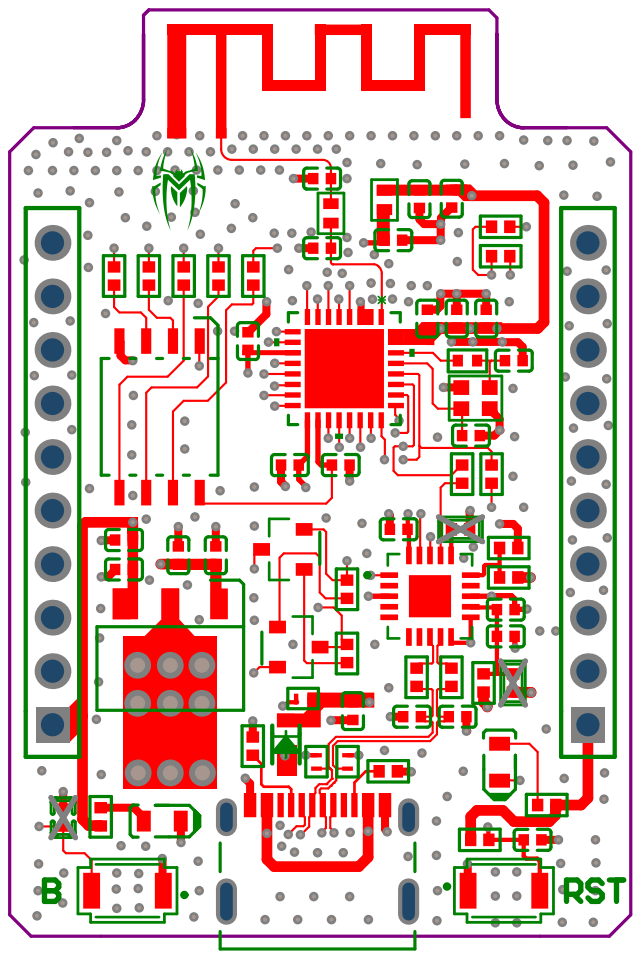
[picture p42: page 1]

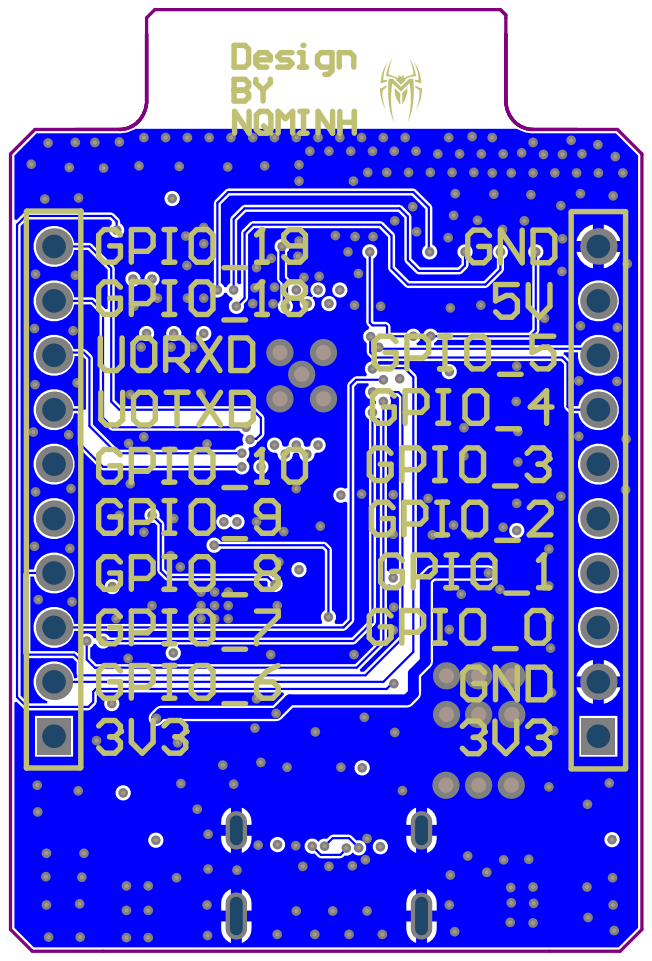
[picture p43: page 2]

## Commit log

2026-04-23 RF continue...
    [B3U-1000P.STEP, B3U-1000P.SchLib, ESP32-C3-RF-V1.0.PrjPcb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]
2026-04-24 arrange component.
    [AQ3045-01ETG.PcbLib, AQ3045-01ETG.SchLib, INDC1006X60N.PcbLib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]
2026-04-25 finish layout.
    [PcbLib.PcbLib, RF.SchDoc, Schlib.SchLib]
2026-05-08 Finish desgin rule check
    [ESP32-C3-RF-V1.0.PrjPcb, PcbLib.PcbLib, USBC-UART.SchDoc]
2026-05-08 Generate Outsource File
    [Bill of Materials-ESP32-C3-RF-V1.0(Variant of ESP32-C3-RF-V1.0).xlsx, ESP32-C3-RF-V1.0.PrjPcb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]
2026-05-08 Add initial README for ESP32_C3_RF project
2026-05-20 fixed Vias
    [PCB-ESP32-C3-RF-V1.0.GBL, PCB-ESP32-C3-RF-V1.0.GBO, PCB-ESP32-C3-RF-V1.0.GBS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]
2026-06-12 export schematic pdf and screencshot image project
    [ESP32-C3-RF-V1.0.PrjPcb, MCU.SchDoc, PCB-ESP32-C3-RF-V1.0.PcbDoc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]
